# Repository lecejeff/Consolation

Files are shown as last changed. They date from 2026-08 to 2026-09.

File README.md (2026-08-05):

# Consolation
Consolation [Console Emulation] project goal is to create a portable emulation device 100% open-source and designed for cost effectiveness and accessibility.

Based on Raspberry Pi Compute Module 5 as core processor

Based on Raspberry Pi RP2350A as joystick controller re-using GP2040-CE FW

Based on Texas Instruments BQ25640 as USB-C PD solution and battery charger

Based on Nuvoton NAU88C22 audio codec

Consolation is a french word for:

1 : the act or an instance of consoling : the state of being consoled : comfort

2 : something that consoles

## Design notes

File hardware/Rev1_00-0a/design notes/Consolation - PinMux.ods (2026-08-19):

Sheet: CM5 MUX
Compute module 5
PIN | Pull? | ALT0 | ALT1 | ALT2 | ALT3 | ALT4 | ALT5 | ALT6 | ALT7 | ALT8 |  |  | Implemented?
GPIO0 | HIGH | SPI0_SIO[3] | DPI_PCLK | UART1_TX | I2C0_SDA |  | SYS_RIO[0] | PROC_RIO[0] | PIO[0] | SPI2_CSn[0] | SDA0 | Normally used for HAT and CSI0 / DSI0. | Yes
GPIO1 | HIGH | SPI0_SIO[2] | DPI_DE | UART1_RX | I2C0_SCL |  | SYS_RIO[1] | PROC_RIO[1] | PIO[1] | SPI2_SIO[1] | SCL0 | Normally used for HAT and CSI0 / DSI0. | Yes
GPIO2 | HIGH | SPI0_CSn[3] | DPI_VSYNC | UART1_CTS | I2C1_SDA | UART0_IR_RX | SYS_RIO[2] | PROC_RIO[2] | PIO[2] | SPI2_SIO[0] | GPIO2 | 1.8V internal pull-up resistors to GPIO_VREF | Yes
GPIO3 | HIGH | SPI0_CSn[2] | DPI_HSYNC | UART1_RTS | I2C1_SCL | UART0_IR_TX | SYS_RIO[3] | PROC_RIO[3] | PIO[3] | SPI2_SCLK | GPIO3 | 1.8V internal pull-up resistors to GPIO_VREF | Yes
GPIO4 | HIGH | GPCLK[0] | DPI_D0 | UART2_TX | I2C2_SDA | UART0_RI | SYS_RIO[4] | PROC_RIO[4] | PIO[4] | SPI3_CSn[0 | SDA2 | System I2C bus | Yes
GPIO5 | HIGH | GPCLK[1] | DPI_D1 | UART2_RX | I2C2_SCL | UART0_DTR | SYS_RIO[5] | PROC_RIO[5] | PIO[5] | SPI3_SIO[1] | SCL2 | System I2C bus | Yes
GPIO6 | HIGH | GPCLK[2] | DPI_D2 | UART2_CTS | I2C3_SDA | UART0_DCD | SYS_RIO[6] | PROC_RIO[6] | PIO[6] | SPI3_SIO[0] | GPIO6 | BAT charger INT input | Yes
GPIO7 | HIGH | SPI0_CSn[1] | DPI_D3 | UART2_RTS | I2C3_SCL | UART0_DSR | SYS_RIO[7] | PROC_RIO[7] | PIO[7] | SPI3_SCLK
GPIO8 | HIGH | SPI0_CSn[0] | DPI_D4 | UART3_TX | I2C0_SDA |  | SYS_RIO[8] | PROC_RIO[8] | PIO[8] | SPI4_CSn[0] | GPIO8 | BT_DISABLE | Yes
GPIO9 | LOW | SPI0_SIO[1] | DPI_D5 | UART3_RX | I2C0_SCL |  | SYS_RIO[9] | PROC_RIO[9] | PIO[9] | SPI4_MISO | GPIO9 | PPS_RTC (WATCHDOG) | Yes
GPIO10 | LOW | SPI0_SIO[0] | DPI_D6 | UART3_CTS | I2C1_SDA |  | SYS_RIO[10] | PROC_RIO[10] | PIO[10] | SPI4_MOSI | GPIO10 | RP2350_USB_BOOT | Yes
GPIO11 | LOW | SPI0_SCLK | DPI_D7 | UART3_RTS | I2C1_SCL |  | SYS_RIO[11] | PROC_RIO[11] | PIO[11] | SPI4_SCLK | GPIO11 | WL_DISABLE
GPIO12 | LOW | PMW0[0] | DPI_D8 | UART4_TX | I2C2_SDA | AUDIO_OUT_L | SYS_RIO[12] | PROC_RIO[12] | PIO[12] | SPI5_CSn[0] | PWM0_0 | MIPI-DSI PWM backlight | Yes
GPIO13 | LOW | PMW0[1] | DPI_D9 | UART4_RX | I2C2_SCL | AUDIO_OUT_R | SYS_RIO[13] | PROC_RIO[13] | PIO[13] | SPI5_SIO[1] | GPIO13 | VOLUME UP BUTTON | Yes
GPIO14 | LOW | PMW0[2] | DPI_D10 | UART4_CTS | I2C3_SDA | UART0_TX | SYS_RIO[14] | PROC_RIO[14] | PIO[14] | SPI5_SIO[0] | TXD0 | UART debug console (native in linux) | Yes
GPIO15 | LOW | PMW0[3] | DPI_D11 | UART4_RTS | I2C3_SCL | UART0_RX | SYS_RIO[15] | PROC_RIO[15] | PIO[15] | SPI5_SCLK | RXD0 | UART debug console (native in linux) | Yes
GPIO16 | LOW | SPI1_CSn[2] | DPI_D12 |  |  | UART0_CTS | SYS_RIO[16] | PROC_RIO[16] | PIO[16] |  | GPIO16 | VOLUME DOWN BUTTON | Yes
GPIO17 | LOW | SPI1_CSn[1] | DPI_D13 |  |  | UART0_RTS | SYS_RIO[17] | PROC_RIO[17] | PIO[17]
GPIO18 | LOW | SPI1_CSn[0] | DPI_D14 | I2S0_SCLK | PWM0[2] | I2S1_SCLK | SYS_RIO[18] | PROC_RIO[18] | PIO[18] | GPCLK[1] | PCM_CLK | I2S NAU8822 | Yes
GPIO19 | LOW | SPI1_SIO[1] | DPI_D15 | I2S0_WS | PWM0[3] | I2S1_WS | SYS_RIO[19] | PROC_RIO[19] | PIO[19] |  | PCM_FS | I2S NAU8822 | Yes
GPIO20 | LOW | SPI1_SIO[0] | DPI_D16 | I2S0_SDI[0] | GPCLK[0] | I2S1_SDI[0] | SYS_RIO[20] | PROC_RIO[20] | PIO[20] |  | PCM_DIN | I2S NAU8822 | Yes
GPIO21 | LOW | SPI1_SCLK | DPI_D17 | I2S0_SDO[0] | GPCLK[1] | I2S1_SDO[0] | SYS_RIO[21] | PROC_RIO[21] | PIO[21] |  | PCM_DOUT | I2S NAU8822 | Yes
GPIO22 | LOW | SDIO0_CLK | DPI_D18 | I2S0_SDI[1] | I2C3_SDA | I2S1_SDI[1] | SYS_RIO[22] | PROC_RIO[22] | PIO[22] |  | GPIO22 | BAT CHRG PG | Yes
GPIO23 | LOW | SDIO0_CMD | DPI_D19 | I2S0_SDO[1] | I2C3_SCL | I2S1_SDO[1] | SYS_RIO[23] | PROC_RIO[23] | PIO[23] |  | GPIO23 | Shutdown control | Yes
GPIO24 | LOW | SDIO0_DAT0 | DPI_D20 | I2S0_SDI[2] |  | I2S1_SDI[2] | SYS_RIO[24] | PROC_RIO[24] | PIO[24] | SPI2_CSn[1]
GPIO25 | LOW | SDIO0_DAT1 | DPI_D21 | I2S0_SDO[2] | AUDIO_IN_CLK | I2S1_SDO[2] | SYS_RIO[25] | PROC_RIO[25] | PIO[25] | SPI3_CSn[1] | GPIO25 | Battery Charger Enable | Yes
GPIO26 | LOW | SDIO0_DAT2 | DPI_D22 | I2S0_SDI[3] | AUDIO_IN_DAT0 | I2S1_SDI[3] | SYS_RIO[26] | PROC_RIO[26] | PIO[26] | SPI5_CSn[1] | GPIO26 | RP2350 Power Enable | Yes
GPIO27 | LOW | SDIO0_DAT3 | DPI_D23 | I2S0_SDO[3] | AUDIO_IN_DAT1 | I2S1_SDO[3] | SYS_RIO[27] | PROC_RIO[27] | PIO[27] | SPI1_CSn[1]

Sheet: RP2350A
PIN # | RP2350A | Used | VDD’s | Crystal + USB | SWD | Joystick + Click | A / B / X / Y | U / D / L / R | L1 / L2 / R1 / R2 | Start / Select | Home / Extra | RPI I2C bus | UART debug | QSPI FLASH
1 | IOVDD | YES | IOVDD
2 | GPIO0 | YES |  |  |  |  |  |  |  |  |  |  | UART0 TX
3 | GPIO1 | YES |  |  |  |  |  |  |  |  |  |  | UART0 RX
4 | GPIO2 | YES |  |  |  |  |  |  |  |  |  | I2C0 SDA
5 | GPIO3 | YES |  |  |  |  |  |  |  |  |  | I2C0 SCL
6 | DVDD | YES | DVDD
7 | GPIO4 | NO
8 | GPIO5 | NO
9 | GPIO6 | YES |  |  |  |  |  |  |  |  | Home
10 | GPIO7 | YES |  |  |  |  |  |  |  |  | Extra
11 | IOVDD | YES | IOVDD
12 | GPIO8 | YES |  |  |  |  |  |  | L1
13 | GPIO9 | YES |  |  |  |  |  |  | L2
14 | GPIO10 | YES |  |  |  |  |  |  | R1
15 | GPIO11 | YES |  |  |  |  |  |  | R2
16 | GPIO12 | YES |  |  |  |  |  | U
17 | GPIO13 | YES |  |  |  |  |  | D
18 | GPIO14 | YES |  |  |  |  |  | L
19 | GPIO15 | YES |  |  |  |  |  | R
20 | IOVDD | YES | IOVDD
21 | XIN | YES |  | XIN
22 | XOUT | YES |  | XOUT
23 | DVDD | YES | DVDD
24 | SWCLK | YES |  |  | SWDCLK
25 | SWDIO | YES |  |  | SWDIO
26 | RUN | YES |  |  | #RESET
27 | GPIO16 | YES |  |  |  |  |  |  |  | Start
28 | GPIO17 | YES |  |  |  |  |  |  |  | Select
29 | GPIO18 | NO
30 | IOVDD | YES | IOVDD
31 | GPIO19 | YES |  |  |  |  | A
32 | GPIO20 | YES |  |  |  |  | B
33 | GPIO21 | YES |  |  |  |  | X
34 | GPIO22 | YES |  |  |  |  | Y
35 | GPIO23 | YES |  |  |  | J1_SW
36 | GPIO24 | YES |  | VBUS_DET
37 | GPIO25 | YES |  |  |  | J2_SW
38 | IOVDD | YES | IOVDD
39 | DVDD | YES | DVDD
40 | GPIO26_ADC0 | YES |  |  |  | J1_X
41 | GPIO27_ADC1 | YES |  |  |  | J1_Y
42 | GPIO28_ADC2 | YES |  |  |  | J2_X
43 | GPIO29_ADC3 | YES |  |  |  | J2_Y
44 | ADC_AVDD | YES | ADC AVDD
45 | IOVDD | YES | IOVDD
46 | VREG_AVDD | YES | VREG AVDD
47 | VREG_PGND | YES | PGND
48 | VREG_LX | YES | VREG LX
49 | VREG_VIN | YES | VREG IN
50 | VREG_FB | YES | VREG FB
51 | USB_DM | YES |  | USB D-
52 | USB_DP | YES |  | USB D+
53 | USB_OTP_VDD | YES | USB VDD
54 | QSPI_IOVDD | YES | QSPI VDD
55 | QSPI_SD3 | YES |  |  |  |  |  |  |  |  |  |  |  | QSPI SD3
56 | QSPI_SCLK | YES |  |  |  |  |  |  |  |  |  |  |  | QSPI SCLK
57 | QSPI_SD0 | YES |  |  |  |  |  |  |  |  |  |  |  | QSPI SD0
58 | QSPI_SD2 | YES |  |  |  |  |  |  |  |  |  |  |  | QSPI SD2
59 | QSPI_SD1 | YES |  |  |  |  |  |  |  |  |  |  |  | QSPI SD1
60 | QSPI_SS | YES |  |  |  |  |  |  |  |  |  |  |  | QSPI SS
 |  | 3

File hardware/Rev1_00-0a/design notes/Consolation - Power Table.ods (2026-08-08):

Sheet: Purpose
Purpose | Engineering documentation to assess power supplies voltage compliance, current draw, power draw, efficiency and estimate margin for Consolation project
Revision | Initial revision 2026-07-19 Author: Jean-Francois Bilodeau, P.Eng #6022173
Project | Consolation [Console Emulation]

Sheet: Dependencies
Consolation [Console Emulation] | Supply name : VBAT |  |  | Consolation [Console Emulation] | VSYS |  |  | Consolation [Console Emulation] | 5V0
Parameters | Min | Nom | Max | Parameters | Min | Nom | Max | Parameters | Min | Nom | Max
Input voltage (V) | N/A | N/A | N/A | Input voltage (V) | 2.750 | 3.700 | 4.200 | Input voltage (V) | 3.520 | 3.750 | 4.000
Input current (mA) | N/A | N/A | N/A | Input current (mA) | 531.020 | 2341.576 | 3738.698 | Input current (mA) | 169.317 | 1490.033 | 2468.688
Quiescent current (mA) | N/A | N/A | N/A | Quiescent current (mA) | 0.8 | 0.9 | 1.4 | Quiescent current (mA) | 0.8 | 0.9 | 1.4
Input power (W) | N/A | N/A | N/A | Input power (W) | 1.460 | 8.664 | 15.703 | Input power (W) | 0.596 | 5.588 | 9.875
Efficiency | N/A | N/A | N/A | Efficiency | 92.00% | 90.00% | 88.00% | Efficiency | 91% | 90% | 90%
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

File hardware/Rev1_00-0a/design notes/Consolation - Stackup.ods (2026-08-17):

90R microstrip differential pair | 90R stripline differential pair
100R microstrip differential pair | 100R stripline differential pair

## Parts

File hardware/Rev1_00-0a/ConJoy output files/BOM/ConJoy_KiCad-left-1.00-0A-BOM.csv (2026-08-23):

Reference | Qty | Value | DNP | Exclude from BOM | Exclude from Board | Footprint | Manufacturer | Manufacturer Part Number | Distributor | Distributor Part Number | Datasheet
C1,C3 | 2 | 1u |  |  |  | footprint:CAP_NONPOL_0805 | YAGEO | CC0805KKX7R9BB105 | DigiKey | 311-1886-1-ND | https://www.yageogroup.com/content/datasheet/asset/file/UPY-GPHC_X7R_6_3V-TO-250V
S1,S2,S3,S4,S5 | 5 | EVQ-Q2P03W |  |  |  | footprint:EVQQ2 | Panasonic Industry | EVQ-Q2P03W | DigiKey | P12949SCT-ND | https://www3.panasonic.biz/ac/cdn/e/control/switch/light-touch/catalog/sw_lt_eng_6s_th.pdf
C2 | 1 | 0.1u |  |  |  | footprint:CAP_NONPOL_0402 | Murata Electronics | GRM155R71H104KE14D | DigiKey | 490-10700-1-ND | https://search.murata.co.jp/Ceramy/image/img/A01X/G101/ENG/GRM155R71H104KE14-01.pdf
J4 | 1 | 5051102291 |  |  |  | footprint:5051102291 | Molex | 5051102291 | DigiKey | WM11288CT-ND | https://www.molex.com/content/dam/molex/molex-dot-com/products/automated/en-us/salesdrawingpdf/505/505110/5051102291_sd.pdf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
J2 | 1 | 0532610271 |  |  |  | footprint:0532610271 | Molex | 0532610271 | DigiKey | WM7620CT-ND | https://www.molex.com/content/dam/molex/molex-dot-com/products/automated/en-us/salesdrawingpdf/532/53261/532610271_sd.pdf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
S6,S7,S8 | 3 | TL1014BF160QG |  |  |  | footprint:TL1014B | E-Switch | TL1014BF160QG | DigiKey | EG5042CT-ND | https://configured-product-images.s3.amazonaws.com/Datasheets/TL1014.pdf
D1 | 1 | MMSZ5226B-7-F |  |  |  | footprint:SOD-123 | Diodes Incorporated | MMSZ5226B-7-F | DigiKey | MMSZ5226B-FDICT-ND | https://www.diodes.com/assets/Datasheets/ds18010.pdf
J3 | 1 | SFV5R-1STE1HLF |  |  |  | footprint:SFV5R-1ST | Amphenol ICC (FCI) | SFV5R-1STE1HLF | DigiKey | 609-4330-1-ND | https://cdn.amphenol-cs.com/media/wysiwyg/files/drawing/10171070.pdf

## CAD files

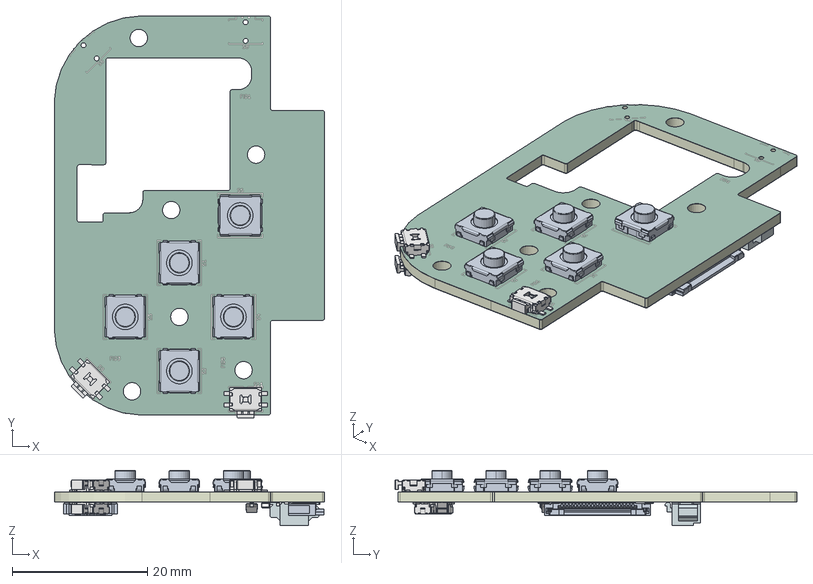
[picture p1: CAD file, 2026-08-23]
hardware/Rev1_00-0a/ConJoy output files/STEP/ConJoy-1.00-0A-STEP-RIGHT.step
40.0 x 59.4 x 8.18 mm
evqq2-bfkpuy-03w_ x 5
TL1014BFxxxQG x 3
sod123
ConJoy-1.00-0A-STEP-RIGHT 1.10
0402_capacitor
0805_cap x 2
ConJoy_KiCad_silkscreen x 2
ConJoy_KiCad_soldermask x 2
ConJoy_KiCad_PCB

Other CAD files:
hardware/Rev1_00-0a/ConJoy output files/STEP/ConJoy-1.00-0A-STEP-LEFT.step

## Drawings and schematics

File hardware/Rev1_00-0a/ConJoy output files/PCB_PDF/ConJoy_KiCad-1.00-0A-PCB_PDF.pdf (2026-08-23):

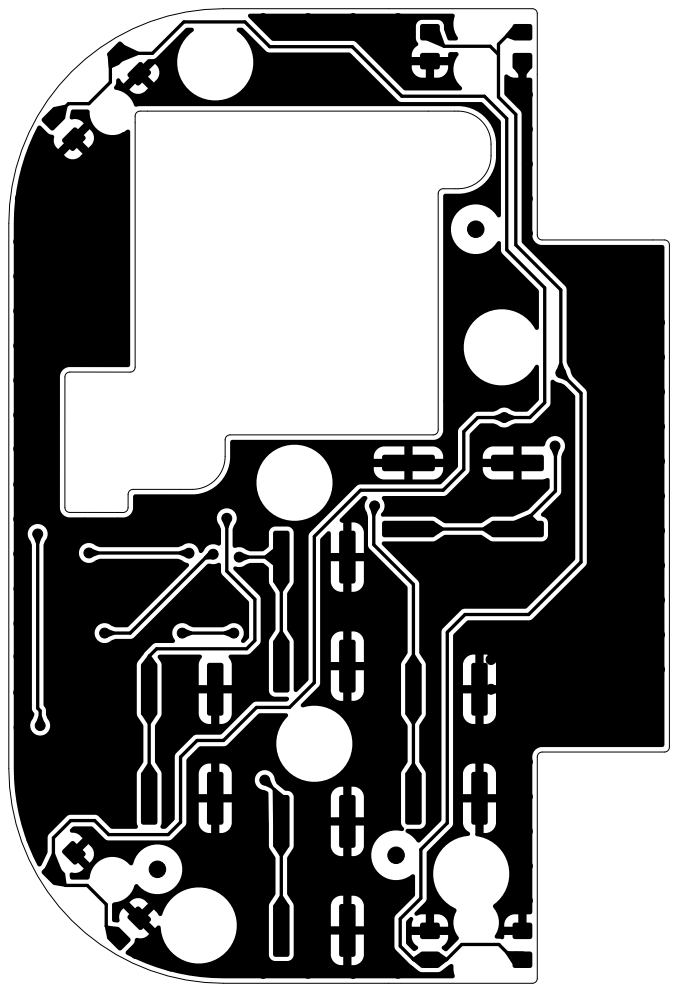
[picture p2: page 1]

Designed by: Jean-Francois Bilodeau P.Eng #6022173 203-1690 rue des quatre-saisons Sherbrooke, Quebec, J1E0N2 KiCad Rev 10.0 Drawn by: Jean-Francois Bilodeau

Date: 2026-08-23 | Current Revision: 1.00-0A Sheet Size: A4 Project: ConJoy [Console Joystick] Sheet: 1 of 9

Sheet Title: ConJoy_KiCad.kicad_pcb | Approved by: Not applicable | Status: In Review

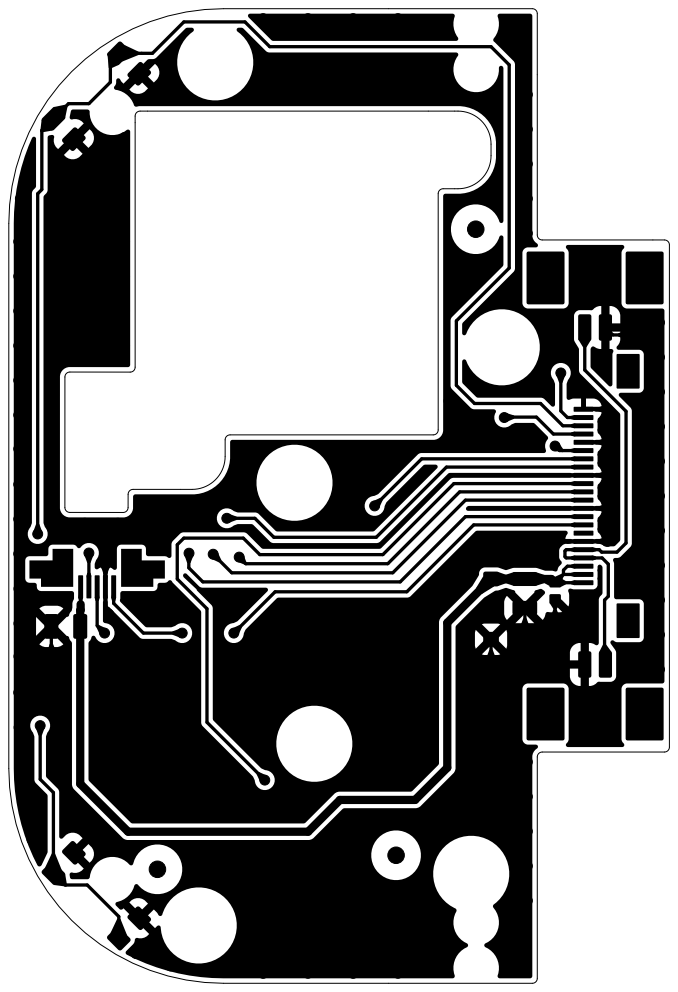
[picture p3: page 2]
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

Date: 2026-08-23 | Current Revision: 1.00-0A Sheet Size: A4 Project: ConJoy [Console Joystick] Sheet: 2 of 9

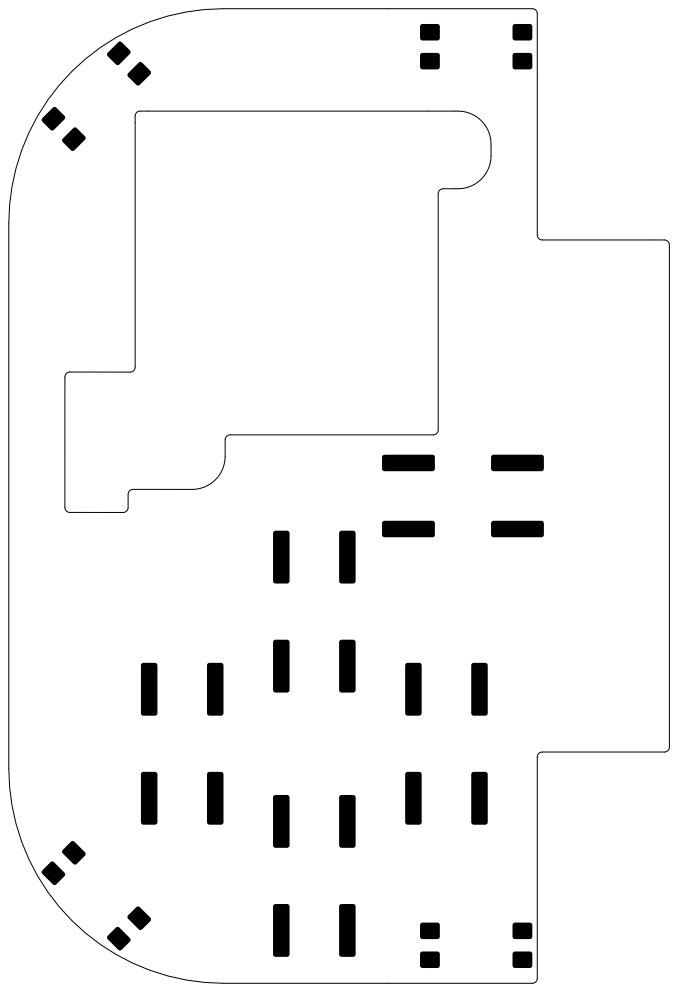
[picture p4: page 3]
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

Date: 2026-08-23 | Current Revision: 1.00-0A Sheet Size: A4 Project: ConJoy [Console Joystick] Sheet: 3 of 9

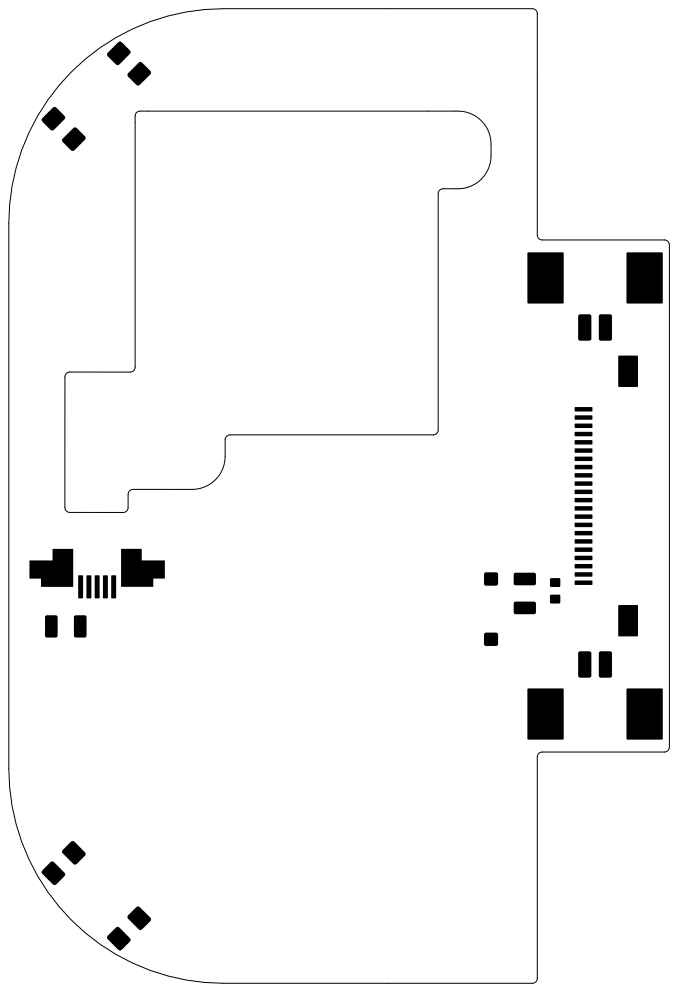
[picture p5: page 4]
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

Date: 2026-08-23 | Current Revision: 1.00-0A Sheet Size: A4 Project: ConJoy [Console Joystick] Sheet: 4 of 9

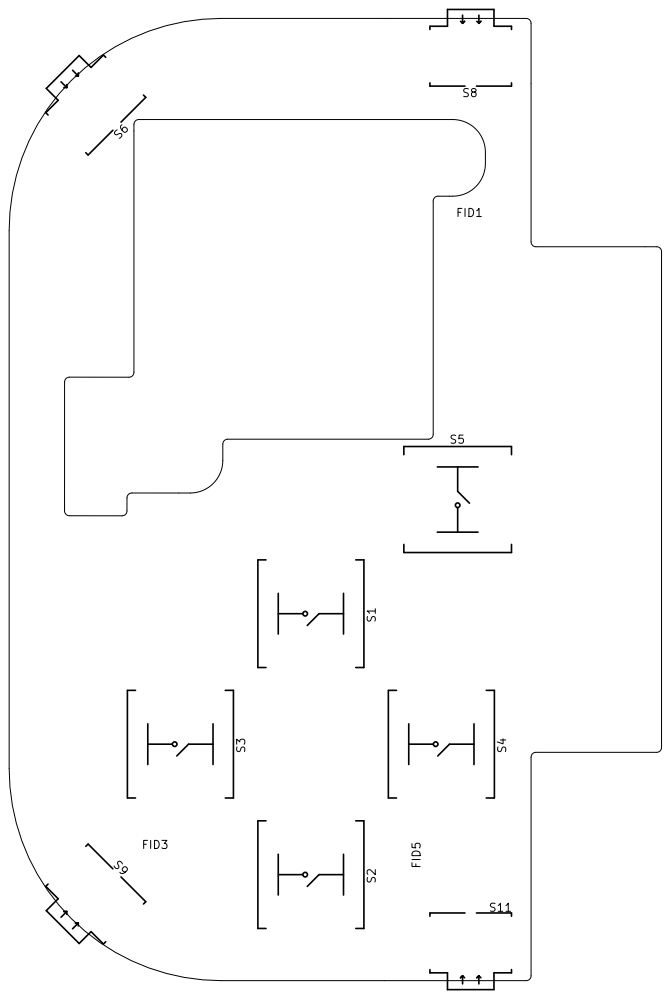
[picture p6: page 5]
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

Date: 2026-08-23 | Current Revision: 1.00-0A Sheet Size: A4 Project: ConJoy [Console Joystick] Sheet: 5 of 9

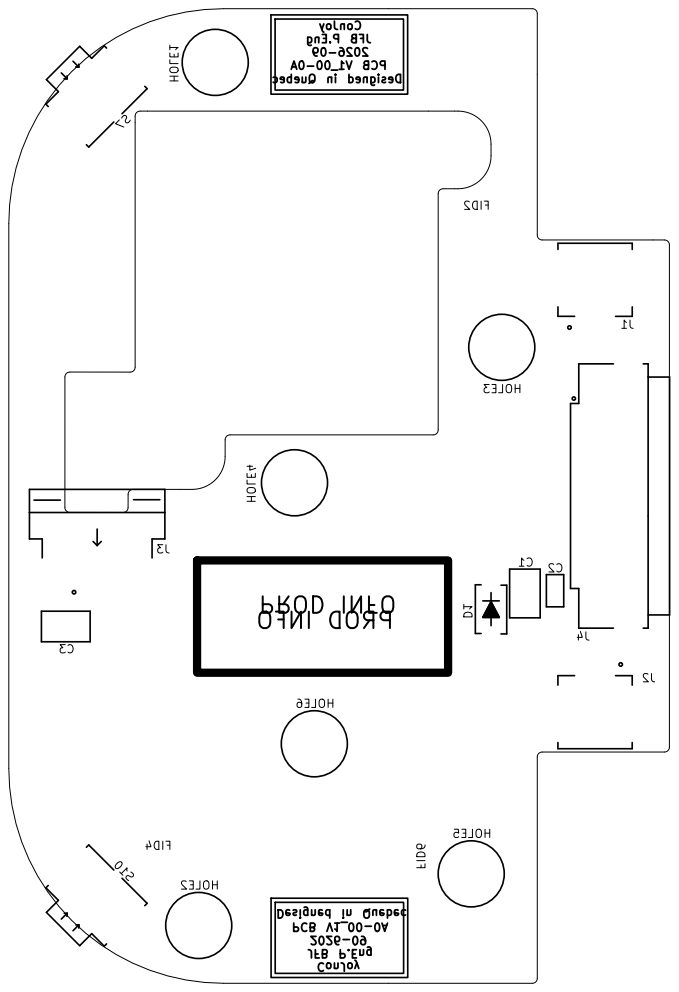
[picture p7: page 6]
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

Date: 2026-08-23 | Current Revision: 1.00-0A Sheet Size: A4 Project: ConJoy [Console Joystick] Sheet: 6 of 9

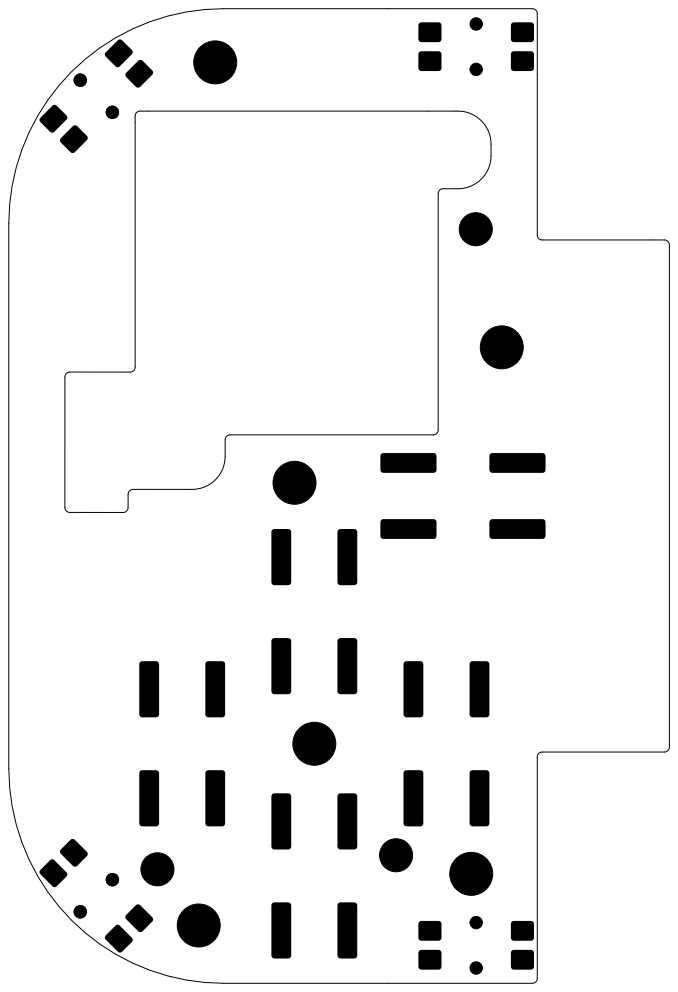
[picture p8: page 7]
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

Date: 2026-08-23 | Current Revision: 1.00-0A Sheet Size: A4 Project: ConJoy [Console Joystick] Sheet: 7 of 9

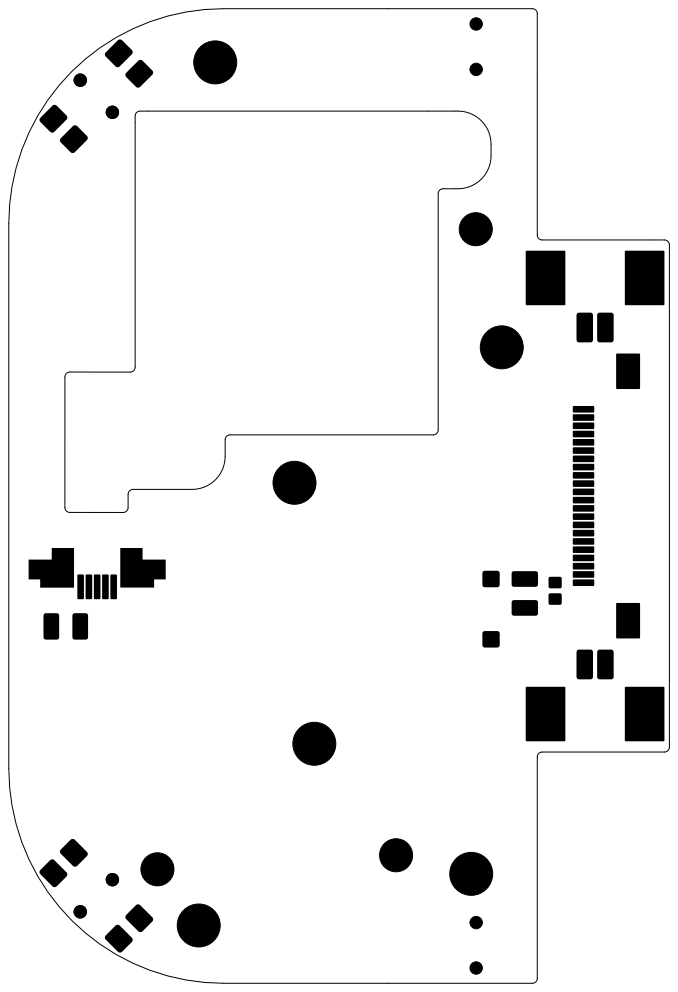
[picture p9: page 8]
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

Date: 2026-08-23 | Current Revision: 1.00-0A Sheet Size: A4 Project: ConJoy [Console Joystick] Sheet: 8 of 9

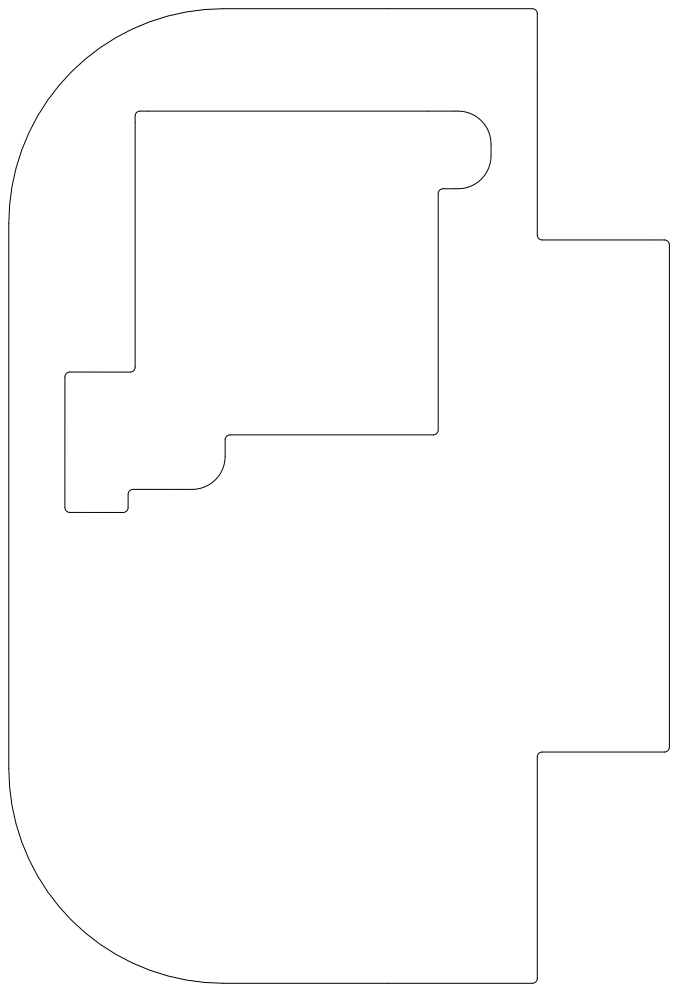
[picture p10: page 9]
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

Date: 2026-08-23 | Current Revision: 1.00-0A Sheet Size: A4 Project: ConJoy [Console Joystick] Sheet: 9 of 9

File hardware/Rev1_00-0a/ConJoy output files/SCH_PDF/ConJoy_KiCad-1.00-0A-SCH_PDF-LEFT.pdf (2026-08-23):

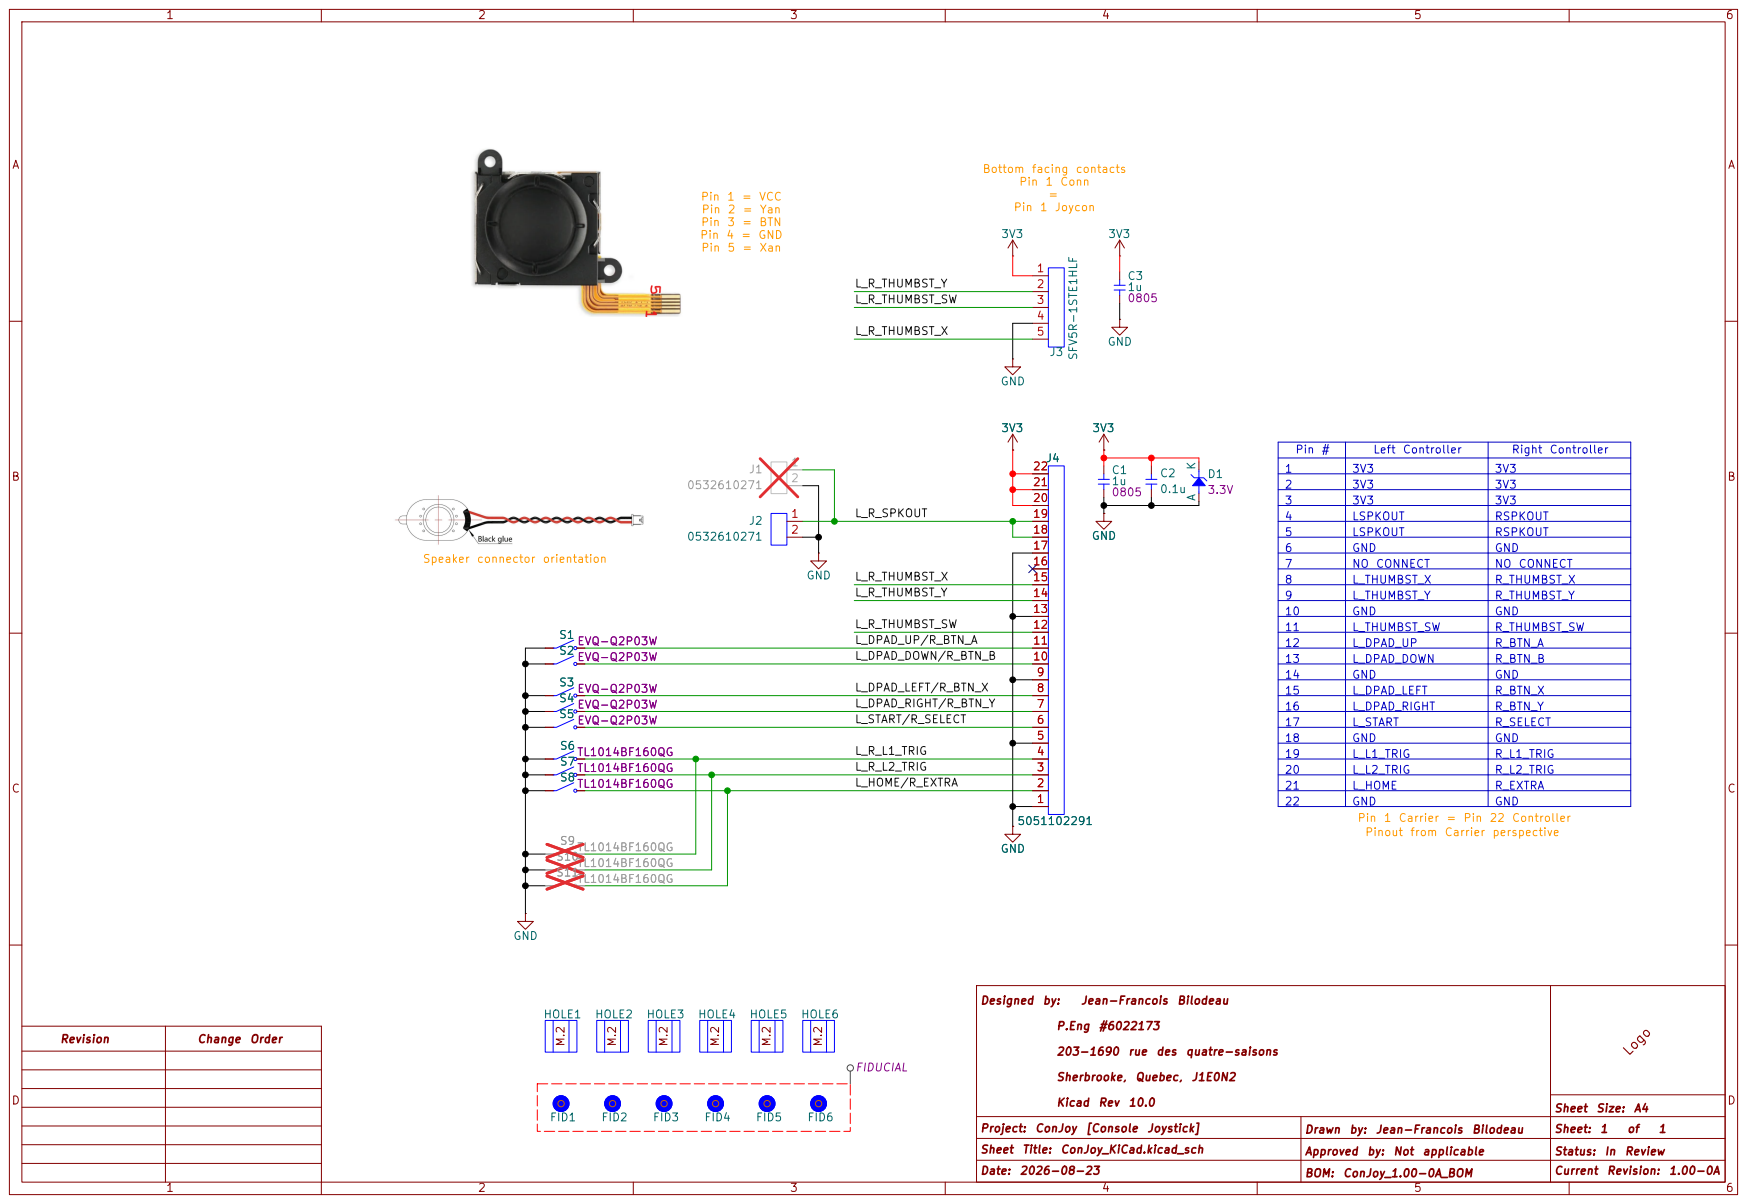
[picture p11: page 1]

Bottom facing contacts Pin 1 Conn =

Pin 1 = VCC
Pin 2 = Yan Pin 3 = BTN

Pin 5 = Xan Speaker connector orientation S3 EVQ-Q2P03W S4 EVQ-Q2P03W S5 EVQ-Q2P03W

20 | L_L2_TRIG | R_L2_TRIG
21 | L_HOME GND | R_EXTRA 22 GND

Pin 1 Carrier = Pin 22 Controller
Pinout from Carrier perspective

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

Date: 2026-08-23 | Current Revision: 1.00-0A Sheet Size: A4 Project: ConJoy [Console Joystick] Sheet: 1 of 1

Sheet Title: ConJoy_KiCad.kicad_sch | Approved by: Not applicable | Status: In Review

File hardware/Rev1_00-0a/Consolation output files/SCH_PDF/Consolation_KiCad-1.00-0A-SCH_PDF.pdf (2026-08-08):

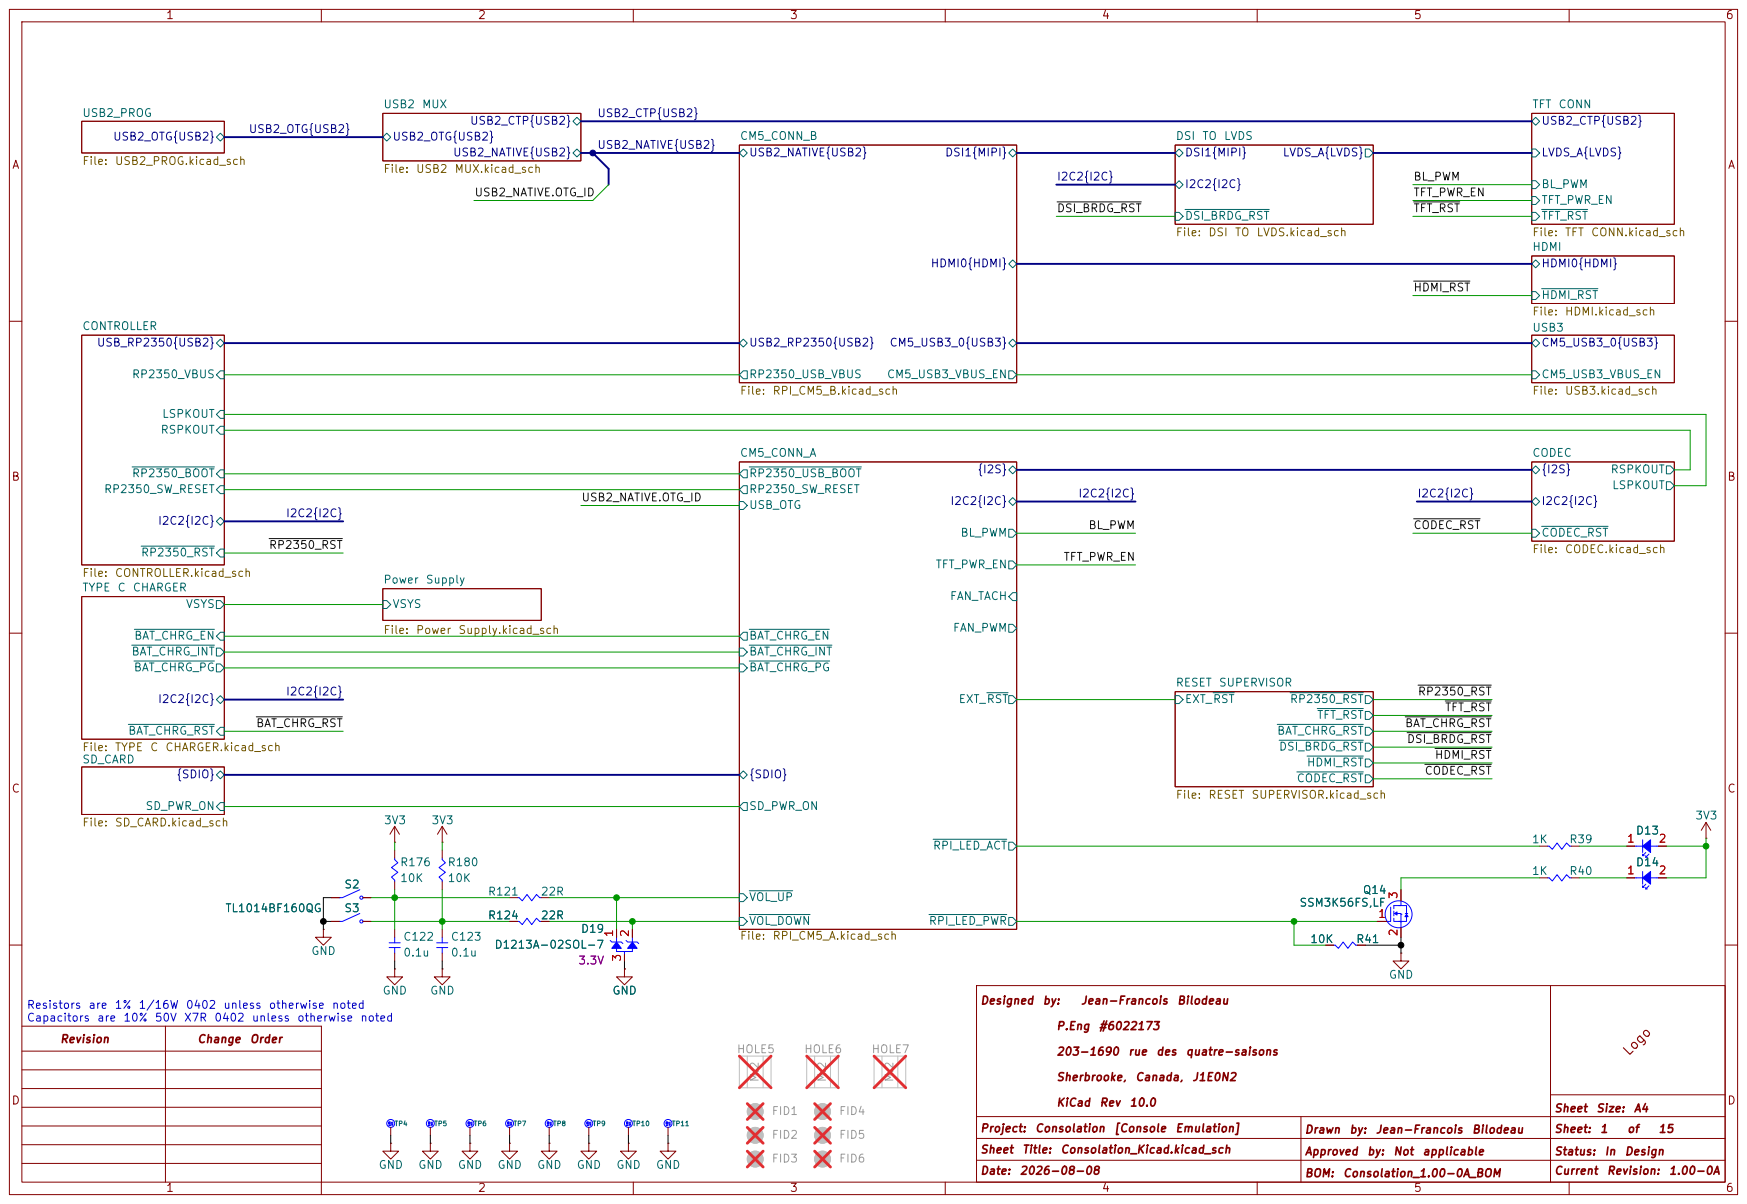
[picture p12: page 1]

HDMI0{HDMI} HDMI_RST HDMI File: HDMI.kicad_sch USB2_CTP{USB2}

File: DSI TO LVDS.kicad_sch BAT_CHRG_EN

Designed by: Jean-Francois Bilodeau P.Eng #6022173 203-1690 rue des quatre-saisons Sherbrooke, Canada, J1E0N2 KiCad Rev 10.0 Drawn by: Jean-Francois Bilodeau

Date: 2026-08-08 | Current Revision: 1.00-0A Sheet Size: A4 Project: Consolation [Console Emulation] Sheet: 1 of 15

Approved by: Not applicable

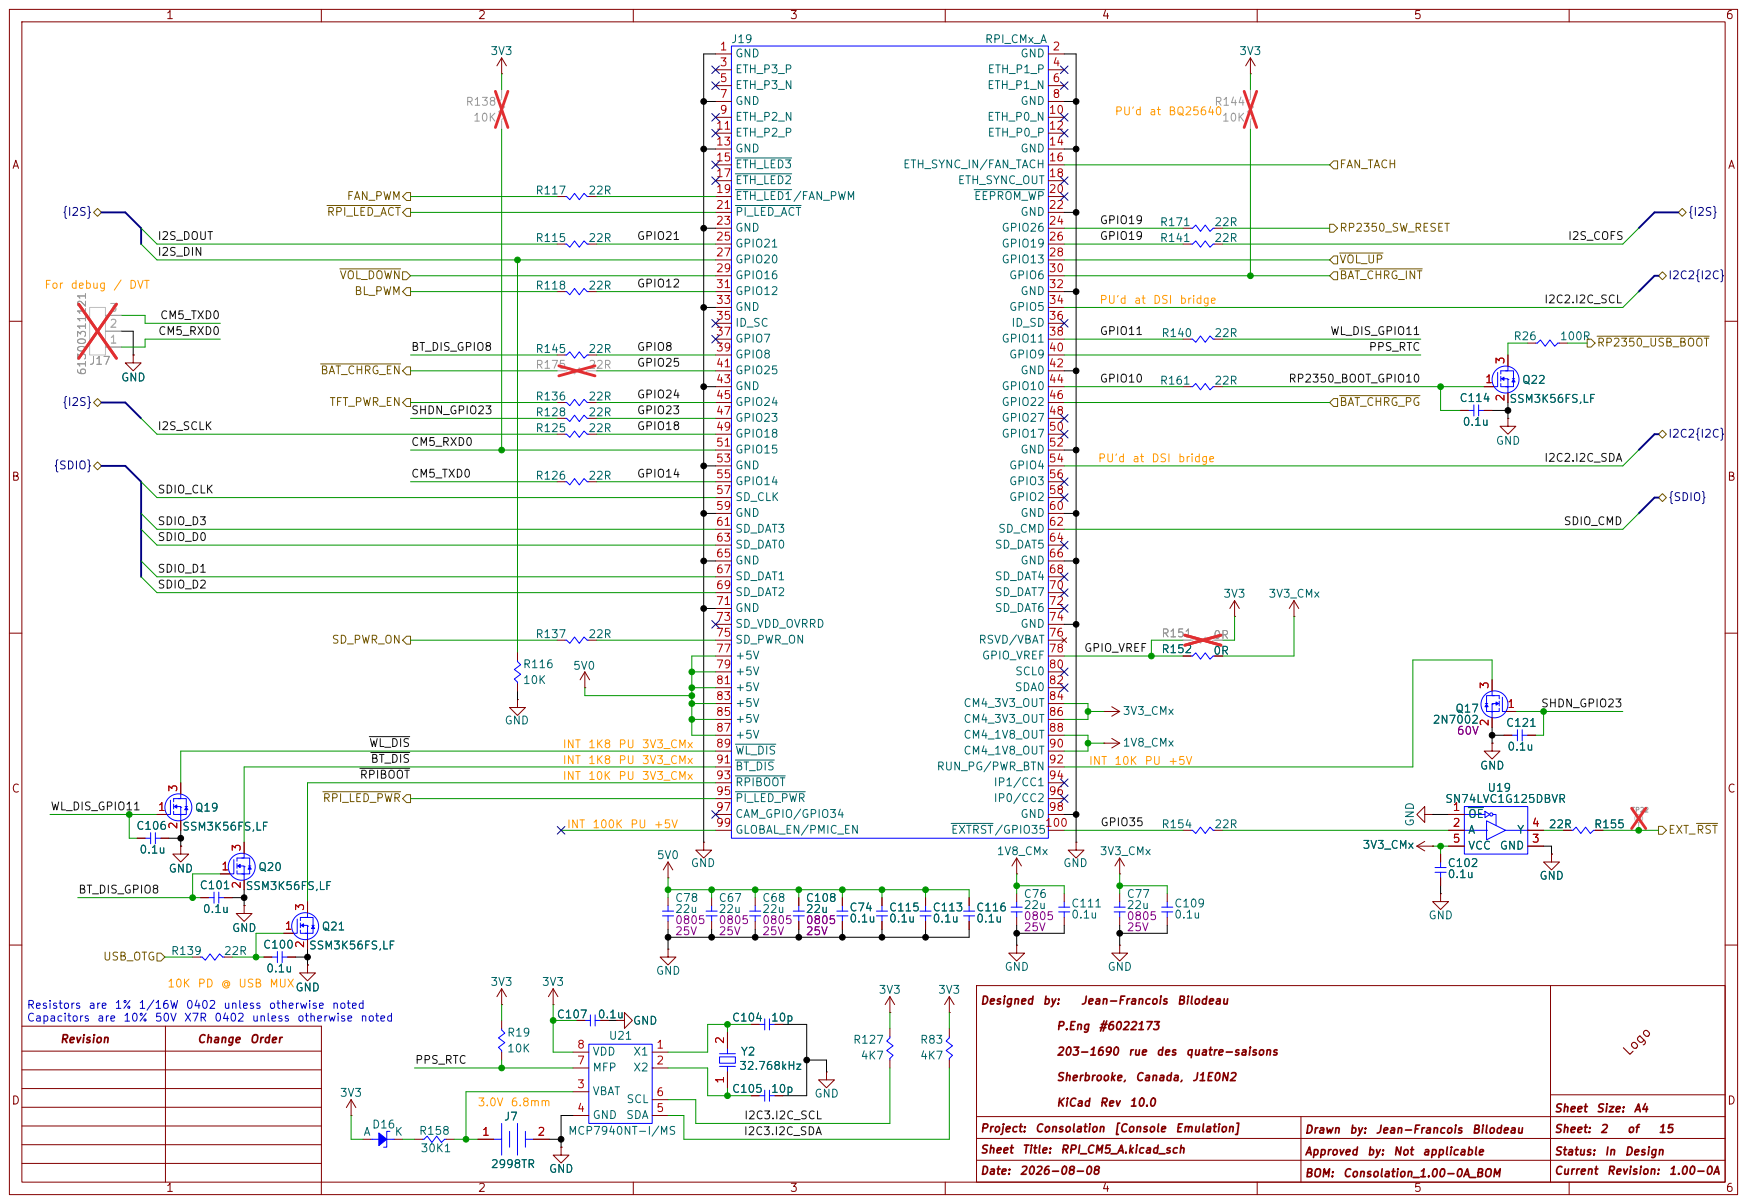
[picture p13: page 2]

INT 1K8 PU 3V3_CMx 10K PD @ USB MUX Resistors are 1% 1/16W 0402 unless otherwise noted Capacitors are 10% 50V X7R 0402 unless otherwise noted

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

Date: 2026-08-08 | Current Revision: 1.00-0A Sheet Size: A4 Project: Consolation [Console Emulation] Sheet: 2 of 15

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

Date: 2026-08-08 | Current Revision: 1.00-0A Sheet Size: A4 Project: Consolation [Console Emulation] Sheet: 3 of 15


Logo HDMI 2.1 D2+ 1 D2S 2 D2- 3 D1+ 4 D1S 5 D1- 6 D0+ 7 D0S 8 D0- 9 CK+ 10 CKS 11 CK- 12 CEC 13 UTIL/HEAC+ 14

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

Date: 2026-08-08 | Current Revision: 1.00-0A Sheet Size: A4 Project: Consolation [Console Emulation] Sheet: 4 of 15

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

Date: 2026-08-08 | Current Revision: 1.00-0A Sheet Size: A4 Project: Consolation [Console Emulation] Sheet: 5 of 15

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

Date: 2026-08-08 | Current Revision: 1.00-0A Sheet Size: A4 Project: Consolation [Console Emulation] Sheet: 6 of 15

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

Date: 2026-08-08 | Current Revision: 1.00-0A Sheet Size: A4 Project: Consolation [Console Emulation] Sheet: 7 of 15


Value TBD Has internal PD

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

Date: 2026-08-08 | Current Revision: 1.00-0A Sheet Size: A4 Project: Consolation [Console Emulation] Sheet: 8 of 15


LSPKOUT USB_RP2350{USB2} RP2350_BOOT RP2350_SW_RESET RP2350_RST
HW reset, push-pull

Pull low before releasing
SW reset to boot USB

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

Date: 2026-08-08 | Current Revision: 1.00-0A Sheet Size: A4 Project: Consolation [Console Emulation] Sheet: 9 of 15


I2C2 PU Pop'd at DSI bridge

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

Date: 2026-08-08 | Current Revision: 1.00-0A Sheet Size: A4 Project: Consolation [Console Emulation] Sheet: 10 of 15

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

Date: 2026-08-08 | Current Revision: 1.00-0A Sheet Size: A4 Project: Consolation [Console Emulation] Sheet: 11 of 15

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

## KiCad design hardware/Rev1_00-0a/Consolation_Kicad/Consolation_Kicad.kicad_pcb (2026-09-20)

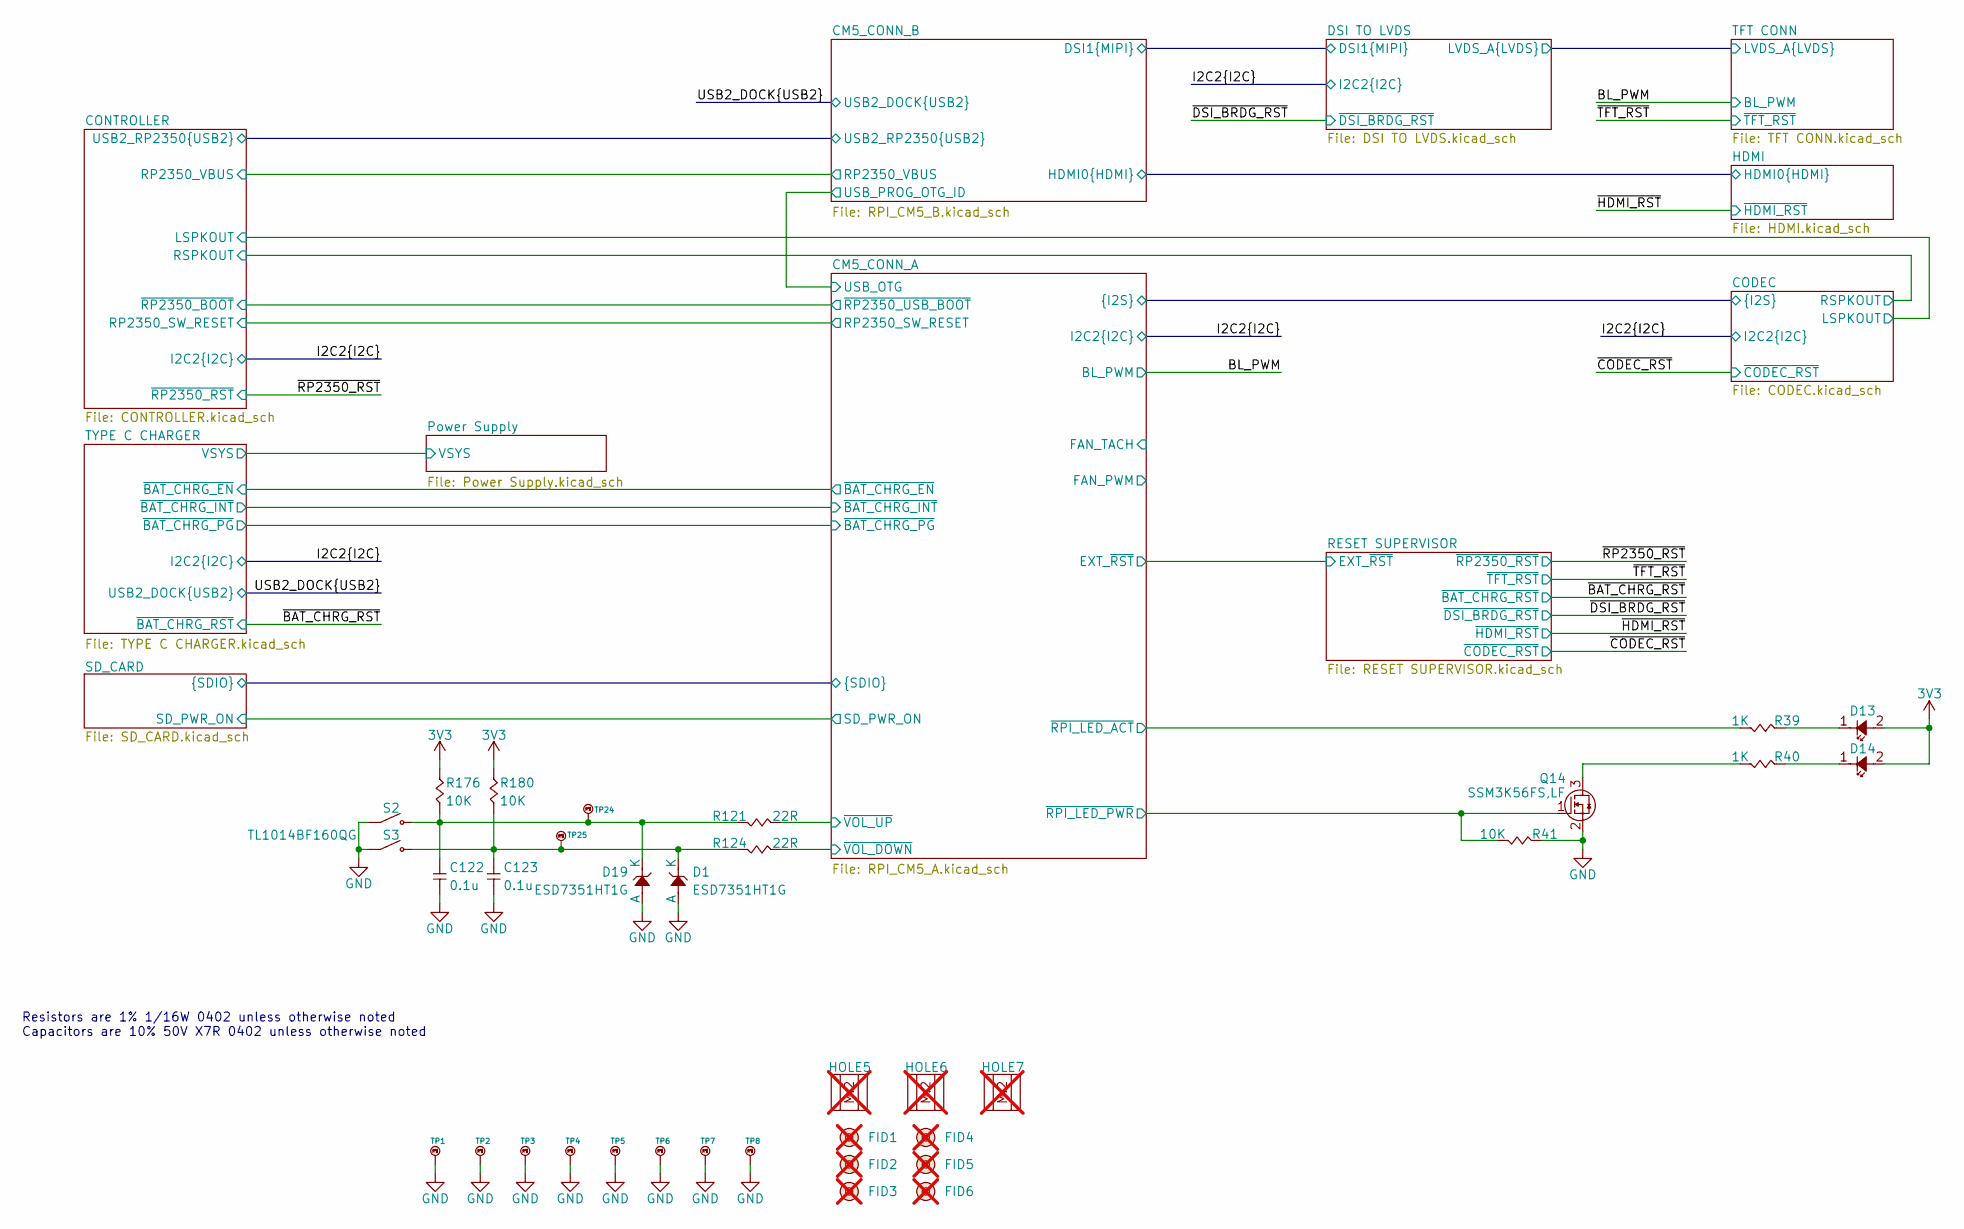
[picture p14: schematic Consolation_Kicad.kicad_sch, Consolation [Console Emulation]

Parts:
C122, C123: 0.1u; CAP_NONPOL_0402; Tolerance ±10%; Voltage Rating 50V; Manufacturer Part Number GRM155R71H104KE14D
D1, D19: ESD7351HT1G; SOD-323; Manufacturer Part Number ESD7351HT1G
D13, D14: LTST-C190KGKT; LED_0603; Tolerance NA; Manufacturer Part Number LTST-C190KGKT
FID1, FID2, FID3, FID4, FID5, FID6: FIDUCIAL; not fitted
HOLE5, HOLE6, HOLE7: NPTH_M2; not fitted
Q14: SSM3K56FS,LF; SC-75; Manufacturer Part Number SSM3K56FS,LF
R39, R40: 1K; RES_0402; Tolerance 1%; Manufacturer Part Number RC0402FR-071KL
R41, R176, R180: 10K; RES_0402; Tolerance 1%; Manufacturer Part Number RC0402FR-0710KL
R121, R124: 22R; RES_0402; Tolerance 1%; Manufacturer Part Number RC0402FR-0722RL
S2, S3: TL1014BF160QG; TL1014B; Manufacturer Part Number TL1014BF160QG
TP1, TP2, TP3, TP4, TP5, TP6, TP7, TP8, TP24, TP25: 75 mils; SMT_TP_75_MILS; Manufacturer Part Number NA

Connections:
3V3: D13.2 (A), D14.2 (A), R176.2, R180.2; also elsewhere on the board
/CM5_CONN_A/~RPI_LED_ACT: R39.2; also elsewhere on the board
/CM5_CONN_A/~RPI_LED_PWR: Q14.1 (G), R41.1; also elsewhere on the board
/CM5_CONN_A/~VOL_DOWN: R124.1; also elsewhere on the board
/CM5_CONN_A/~VOL_UP: R121.1; also elsewhere on the board
GND: C122.1, C123.1, D1.2 (A), D19.2 (A), Q14.2 (S), R41.2, S2.1, S3.1, TP1.1, TP2.1, TP3.1, TP4.1, TP5.1, TP6.1, TP7.1, TP8.1; also elsewhere on the board
unnamed: C123.2, D1.1 (K), R124.2, R180.1, S3.2, TP25.1
unnamed: D13.1 (K), R39.1
unnamed: D14.1 (K), R40.1
unnamed: C122.2, D19.1 (K), R121.2, R176.1, S2.2, TP24.1
unnamed: Q14.3 (D), R40.2

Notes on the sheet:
Resistors are 1% 1/16W 0402 unless otherwise noted Capacitors are 10% 50V X7R 0402 unless otherwise noted

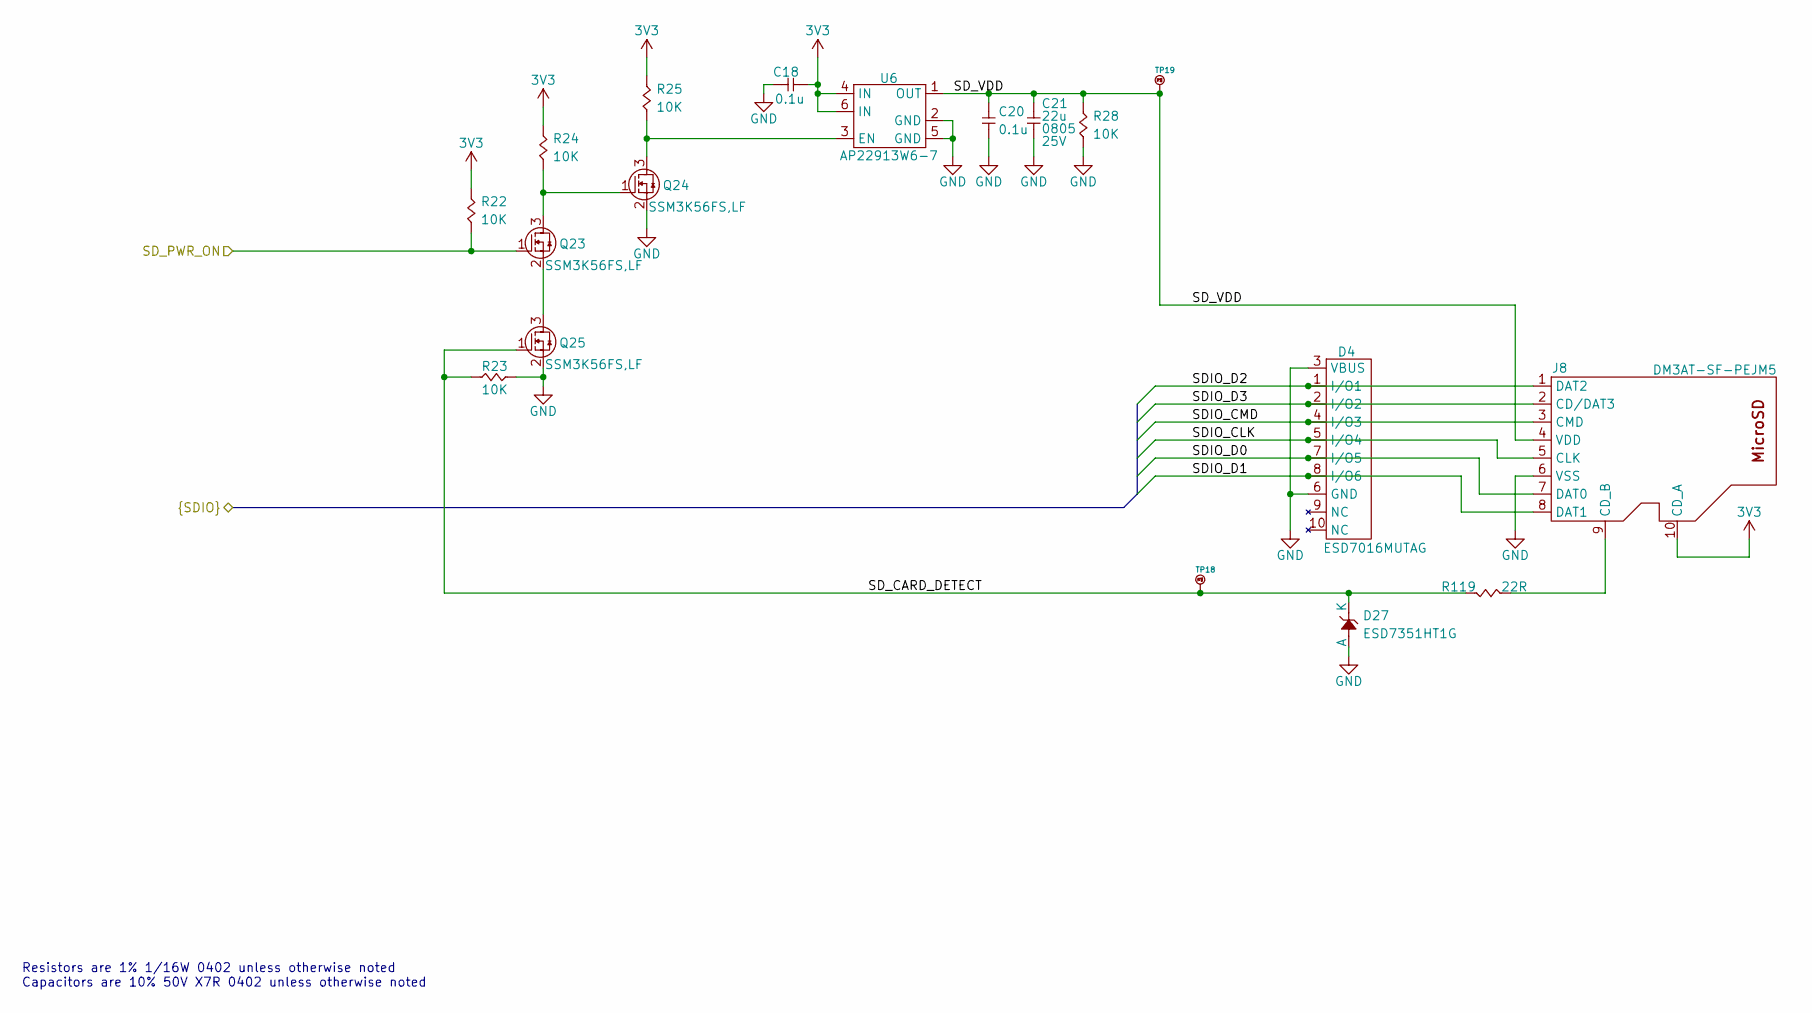
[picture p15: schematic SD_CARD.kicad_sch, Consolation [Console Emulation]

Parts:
C18, C20: 0.1u; CAP_NONPOL_0402; Tolerance ±10%; Voltage Rating 50V; Manufacturer Part Number GRM155R71H104KE14D
C21: 22u; CAP_NONPOL_0805; Tolerance ±20%; Voltage Rating 25V; Manufacturer Part Number CL21A226MAYNNNE
D4: ESD7016MUTAG; UDFN8; Manufacturer Part Number ESD7016MUTAG
D27: ESD7351HT1G; SOD-323; Manufacturer Part Number ESD7351HT1G
J8: DM3AT-SF-PEJM5; Current Rating 0.5A; Voltage Rating 125V; Manufacturer Part Number DM3AT-SF-PEJM5
Q23, Q24, Q25: SSM3K56FS,LF; SC-75; Manufacturer Part Number SSM3K56FS,LF
R22, R23, R24, R25, R28: 10K; RES_0402; Tolerance 1%; Manufacturer Part Number RC0402FR-0710KL
R119: 22R; RES_0402; Tolerance 1%; Manufacturer Part Number RC0402FR-0722RL
TP18, TP19: 75 mils; SMT_TP_75_MILS; Manufacturer Part Number NA
U6: AP22913W6-7; SOT-23-6; Load Voltage 1.5V ~ 5.5V; Manufacturer Part Number AP22913W6-7

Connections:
3V3: C18.2, J8.10 (CD_A), R22.2, R24.2, R25.2, U6.4 (IN), U6.6 (IN); also elsewhere on the board
/CM5_CONN_A/SDIO_CLK: D4.5 (I/O4), J8.5 (CLK); also elsewhere on the board
/CM5_CONN_A/SDIO_CMD: D4.4 (I/O3), J8.3 (CMD); also elsewhere on the board
/CM5_CONN_A/SDIO_D0: D4.7 (I/O5), J8.7 (DAT0); also elsewhere on the board
/CM5_CONN_A/SDIO_D1: D4.8 (I/O6), J8.8 (DAT1); also elsewhere on the board
/CM5_CONN_A/SDIO_D2: D4.1 (I/O1), J8.1 (DAT2); also elsewhere on the board
/CM5_CONN_A/SDIO_D3: D4.2 (I/O2), J8.2 (CD/DAT3); also elsewhere on the board
/CM5_CONN_A/SD_PWR_ON: Q23.1 (G), R22.1; also elsewhere on the board
/SD_CARD/SD_CARD_DETECT: D27.1 (K), Q25.1 (G), R23.2, R119.2, TP18.1
/SD_CARD/SD_VDD: C20.2, C21.2, J8.4 (VDD), R28.2, TP19.1, U6.1 (OUT)
GND: C18.1, C20.1, C21.1, D4.3 (VBUS), D4.6 (GND), D27.2 (A), J8.6 (VSS), Q24.2 (S), Q25.2 (S), R23.1, R28.1, U6.2 (GND), U6.5 (GND); also elsewhere on the board
unnamed: J8.9 (CD_B), R119.1
unnamed: Q23.3 (D), Q24.1 (G), R24.1
unnamed: Q23.2 (S), Q25.3 (D)
unnamed: Q24.3 (D), R25.1, U6.3 (EN)

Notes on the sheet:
Resistors are 1% 1/16W 0402 unless otherwise noted Capacitors are 10% 50V X7R 0402 unless otherwise noted

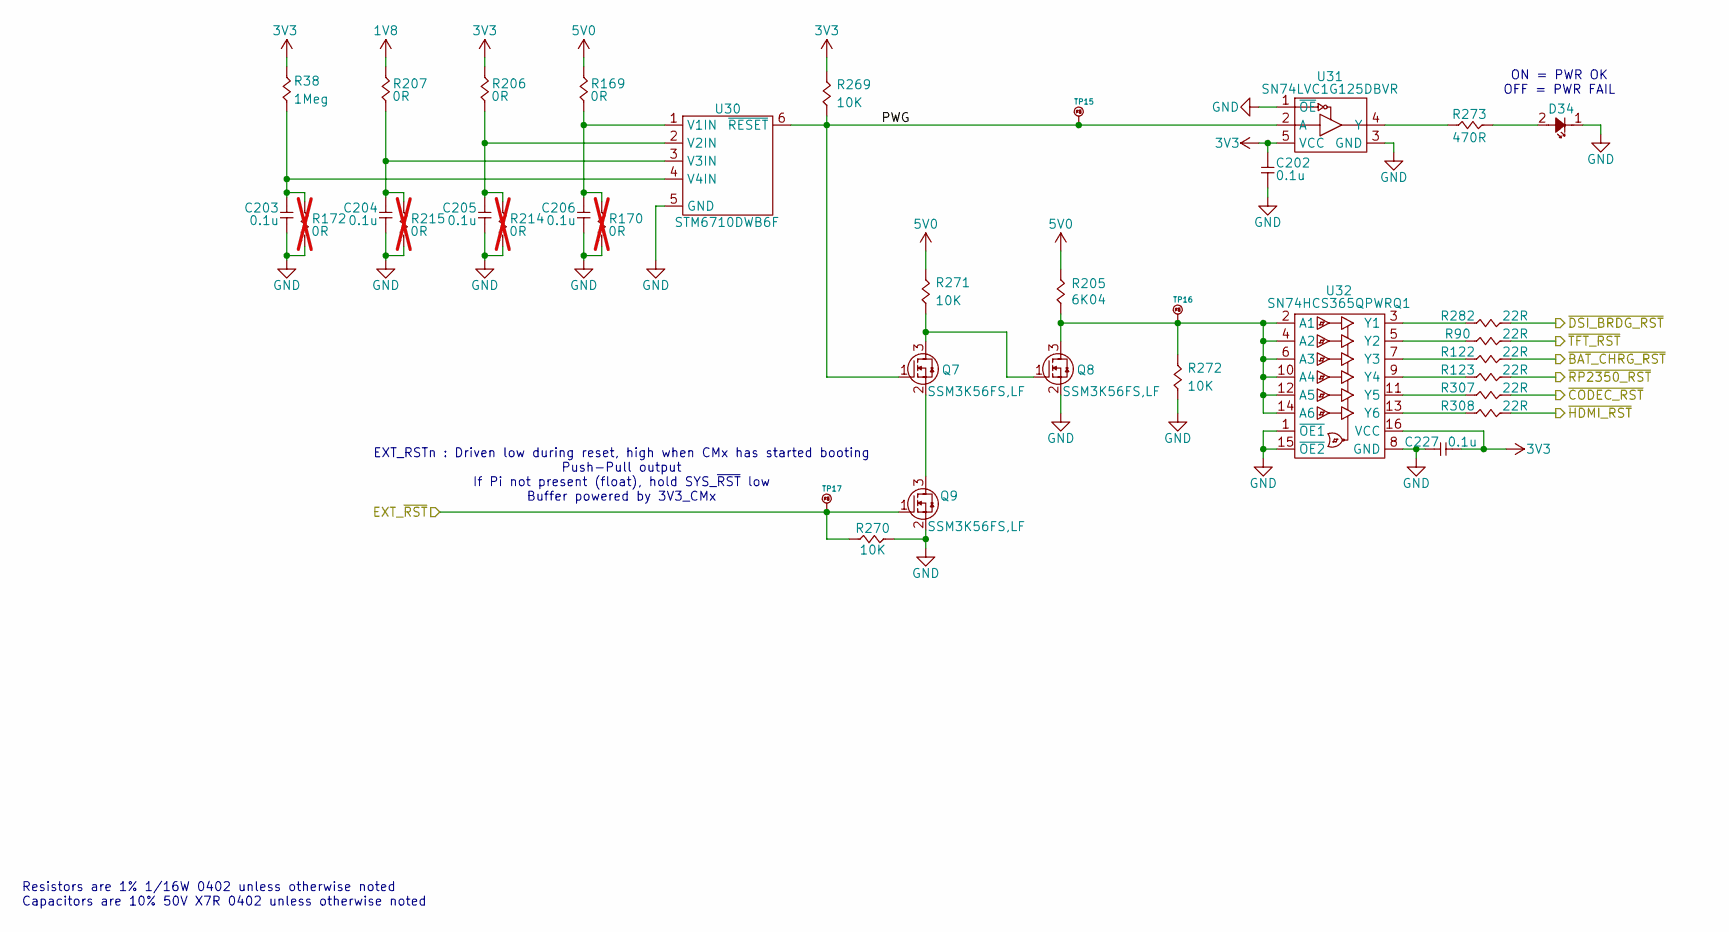
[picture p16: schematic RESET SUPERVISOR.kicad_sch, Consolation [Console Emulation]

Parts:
C202, C203, C204, C205, C206, C227: 0.1u; CAP_NONPOL_0402; Tolerance ±10%; Voltage Rating 50V; Manufacturer Part Number GRM155R71H104KE14D
D34: LTST-C190KGKT; LED_0603; Tolerance NA; Manufacturer Part Number LTST-C190KGKT
Q7, Q8, Q9: SSM3K56FS,LF; SC-75; Manufacturer Part Number SSM3K56FS,LF
R38: 1Meg; RES_0402; Tolerance 1%; Manufacturer Part Number RC0402FR-131ML
R90, R122, R123, R282, R307, R308: 22R; RES_0402; Tolerance 1%; Manufacturer Part Number RC0402FR-0722RL
R169, R206, R207: 0R; RES_0402; Tolerance 1%; Manufacturer Part Number RC0402FR-071KL
R170, R172, R214, R215: 0R; RES_0402; Tolerance 1%; Manufacturer Part Number RC0402FR-071KL; not fitted
R205: 6K04; RES_0402; Tolerance 1%; Manufacturer Part Number RC0402FR-076K04P
R269, R270, R271, R272: 10K; RES_0402; Tolerance 1%; Manufacturer Part Number RC0402FR-0710KL
R273: 470R; RES_0402; Tolerance 1%; Manufacturer Part Number RC0402FR-07470RL
TP15, TP16, TP17: 75 mils; SMT_TP_75_MILS; Manufacturer Part Number NA
U30: STM6710DWB6F; SOT-23-6; Supply Voltage 1.20V ~ 5.5V; Manufacturer Part Number STM6710DWB6F
U31: SN74LVC1G125DBVR; SOT-23-5; Supply Voltage 1.65V ~ 5.5V; Manufacturer Part Number SN74LVC1G125DBVR
U32: SN74HCS365QPWRQ1; TSSOP-16-5.8mm; Supply Voltage 2.0V ~ 6.0V; Manufacturer Part Number SN74HCS365QPWRQ1

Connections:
1V8: R207.2; also elsewhere on the board
3V3: C202.2, C227.1, R38.2, R206.2, R269.2, U31.5 (VCC), U32.16 (VCC); also elsewhere on the board
5V0: R169.2, R205.1, R271.2; also elsewhere on the board
/CM5_CONN_A/EXT_~RST: Q9.1 (G), R270.2, TP17.1; also elsewhere on the board
/RESET SUPERVISOR/PWG: Q7.1 (G), R269.1, TP15.1, U30.6 (~RESET), U31.2 (A)
/~BAT_CHRG_RST: R122.2; also elsewhere on the board
/~CODEC_RST: R307.2; also elsewhere on the board
/~DSI_BRDG_RST: R282.2; also elsewhere on the board
/~HDMI_RST: R308.2; also elsewhere on the board
/~RP2350_RST: R123.2; also elsewhere on the board
/~TFT_RST: R90.2; also elsewhere on the board
GND: C202.1, C203.1, C204.1, C205.1, C206.1, C227.2, D34.1 (K), Q8.2 (S), Q9.2 (S), R170.1, R172.1, R214.1, R215.1, R270.1, R272.1, U30.5 (GND), U31.1 (~OE), U31.3 (GND), U32.1 (~OE1), U32.8 (GND), U32.15 (~OE2); also elsewhere on the board
unnamed: D34.2 (A), R273.2
unnamed: Q7.3 (D), Q8.1 (G), R271.1
unnamed: Q7.2 (S), Q9.3 (D)
unnamed: Q8.3 (D), R205.2, R272.2, TP16.1, U32.2 (A1), U32.4 (A2), U32.6 (A3), U32.10 (A4), U32.12 (A5), U32.14 (A6)
unnamed: C206.2, R169.1, R170.2, U30.1 (V1IN)
unnamed: C205.2, R206.1, R214.2, U30.2 (V2IN)
unnamed: C204.2, R207.1, R215.2, U30.3 (V3IN)
unnamed: C203.2, R38.1, R172.2, U30.4 (V4IN)
unnamed: R273.1, U31.4 (Y)
unnamed: R282.1, U32.3 (Y1)
unnamed: R90.1, U32.5 (Y2)
unnamed: R122.1, U32.7 (Y3)
unnamed: R123.1, U32.9 (Y4)
unnamed: R307.1, U32.11 (Y5)
unnamed: R308.1, U32.13 (Y6)

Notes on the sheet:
EXT_RSTn : Driven low during reset, high when CMx has started booting Push-Pull output If Pi not present (float), hold SYS_~{RST} low Buffer powered by 3V3_CMx
ON = PWR OK OFF = PWR FAIL
Resistors are 1% 1/16W 0402 unless otherwise noted Capacitors are 10% 50V X7R 0402 unless otherwise noted

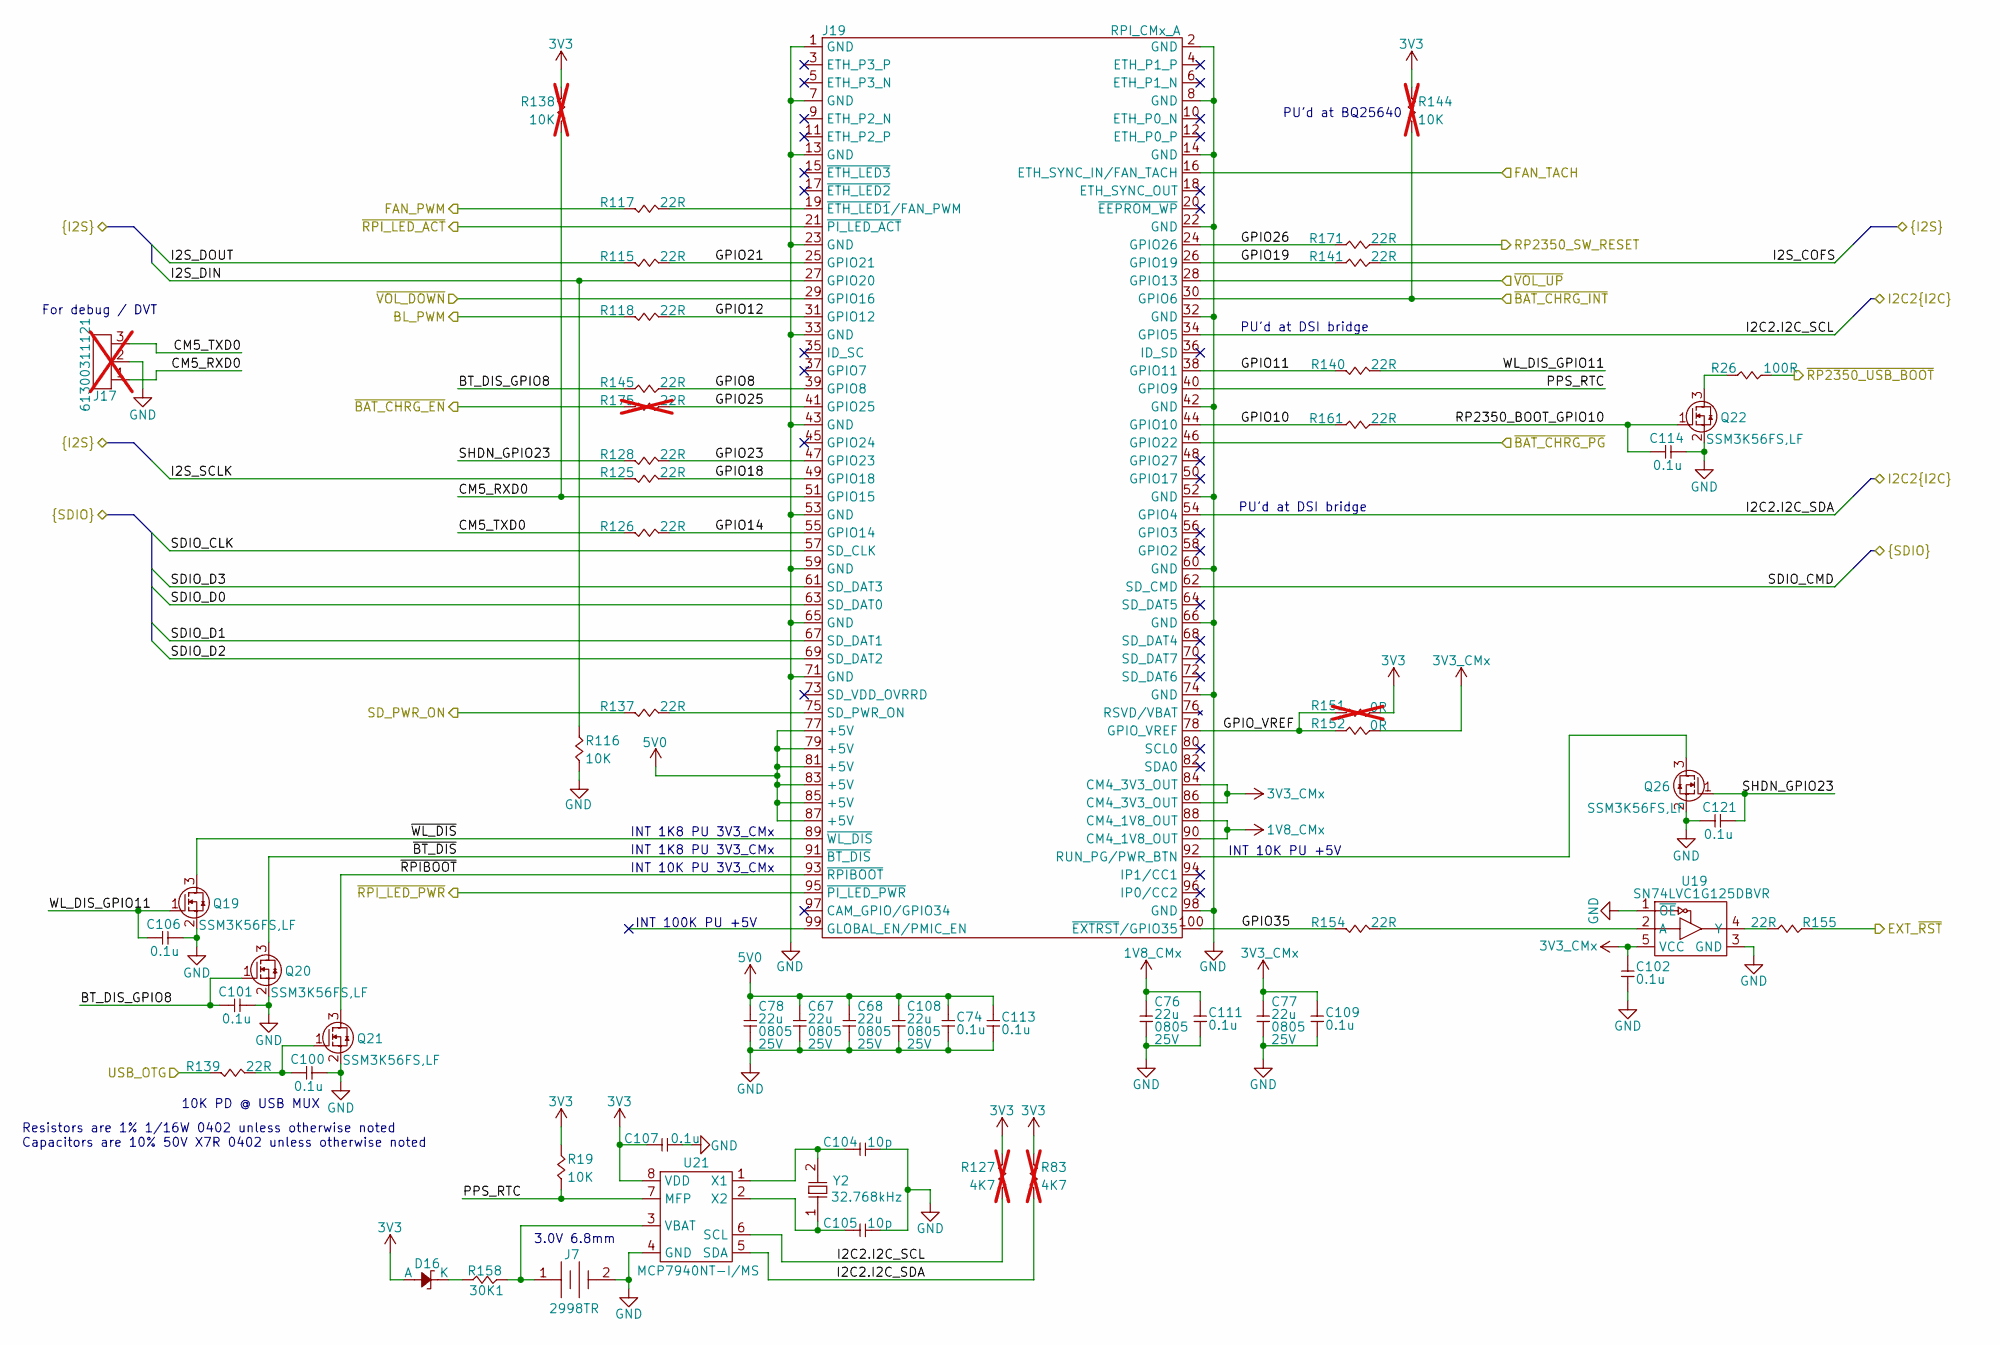
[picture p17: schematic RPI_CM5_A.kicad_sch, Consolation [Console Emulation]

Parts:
C67, C68, C76, C77, C78, C108: 22u; CAP_NONPOL_0805; Tolerance ±20%; Voltage Rating 25V; Manufacturer Part Number CL21A226MAYNNNE
C74, C100, C101, C102, C106, C107, C109, C111, C113, C114, C121: 0.1u; CAP_NONPOL_0402; Tolerance ±10%; Voltage Rating 50V; Manufacturer Part Number GRM155R71H104KE14D
C104, C105: 10p; CAP_NONPOL_0402; Tolerance ±5%; Voltage Rating 50V; Manufacturer Part Number CC0402JRNPO9BN100
D16: BAT42WS-TP; SOD-323; Tolerance NA; Manufacturer Part Number BAT42WS-TP
J7: 2998TR; Manufacturer Part Number 2998TR
J17: 61300311121; HEADER_3P_2_54MM; Voltage Rating 250V; Current Rating 3A; Manufacturer Part Number 61300311121; not fitted
J19: RPI_CMx_A; DF40HC(3.0)-100DS-0.4V; Current Rating 0.5A; Voltage Rating 150V; Manufacturer Part Number DF40HC(3.0)-100DS-0.4V(58)
Q19, Q20, Q21, Q22, Q26: SSM3K56FS,LF; SC-75; Manufacturer Part Number SSM3K56FS,LF
R19, R116: 10K; RES_0402; Tolerance 1%; Manufacturer Part Number RC0402FR-0710KL
R26: 100R; RES_0402; Tolerance 1%; Manufacturer Part Number RC0402FR-07100RL
R83, R127: 4K7; RES_0402; Tolerance 1%; Manufacturer Part Number RC0402FR-074K7L; not fitted
R115, R117, R118, R125, R126, R128, R137, R139, R140, R141, R145, R154, R155, R161, R171: 22R; RES_0402; Tolerance 1%; Manufacturer Part Number RC0402FR-0722RL
R138, R144: 10K; RES_0402; Tolerance 1%; Manufacturer Part Number RC0402FR-0710KL; not fitted
R151: 0R; RES_0402; Tolerance 1%; Manufacturer Part Number RC0402FR-071KL; not fitted
R152: 0R; RES_0402; Tolerance 1%; Manufacturer Part Number RC0402FR-071KL
R158: 30K1; RES_0402; Tolerance 1%; Manufacturer Part Number RC0402FR-0730K1L
R175: 22R; RES_0402; Tolerance 1%; Manufacturer Part Number RC0402FR-0722RL; not fitted
U19: SN74LVC1G125DBVR; SOT-23-5; Supply Voltage 1.65V ~ 5.5V; Manufacturer Part Number SN74LVC1G125DBVR
U21: MCP7940NT-I/MS; MSOP-8; Supply Voltage 1.8V ~ 5.5V; Manufacturer Part Number MCP7940NT-I/MS
Y2: 32.768kHz; 2-SMD_3_2mmx1_5mm; Tolerance ±20ppm; Manufacturer Part Number ABS07-32.768KHZ-7-T

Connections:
1V8_CMx: C76.2, C111.2, J19.88 (CM4_1V8_OUT), J19.90 (CM4_1V8_OUT)
3V3: C107.1, D16.2 (A), R19.2, R83.2, R127.2, R138.2, R144.2, R151.2, U21.8 (VDD); also elsewhere on the board
3V3_CMx: C77.2, C102.2, C109.2, J19.84 (CM4_3V3_OUT), J19.86 (CM4_3V3_OUT), R152.2, U19.5 (VCC); also elsewhere on the board
5V0: C67.2, C68.2, C74.2, C78.2, C108.2, C113.2, J19.77 (+5V), J19.79 (+5V), J19.81 (+5V), J19.83 (+5V), J19.85 (+5V), J19.87 (+5V); also elsewhere on the board
/BL_PWM: R118.2; also elsewhere on the board
/CM5_CONN_A/BT_DIS_GPIO8: C101.2, Q20.1 (G), R145.1
/CM5_CONN_A/CM5_RXD0: J17.1, J19.51 (GPIO15), R138.1
/CM5_CONN_A/CM5_TXD0: J17.3, R126.2
/CM5_CONN_A/EXT_~RST: R155.2; also elsewhere on the board
/CM5_CONN_A/FAN_PWM: R117.2
/CM5_CONN_A/FAN_TACH: J19.16 (ETH_SYNC_IN/FAN_TACH)
/CM5_CONN_A/GPIO8: J19.39 (GPIO8), R145.2
/CM5_CONN_A/GPIO10: J19.44 (GPIO10), R161.1
/CM5_CONN_A/GPIO11: J19.38 (GPIO11), R140.2
/CM5_CONN_A/GPIO12: J19.31 (GPIO12), R118.1
/CM5_CONN_A/GPIO14: J19.55 (GPIO14), R126.1
/CM5_CONN_A/GPIO18: J19.49 (GPIO18), R125.1
/CM5_CONN_A/GPIO19: J19.26 (GPIO19), R141.1
/CM5_CONN_A/GPIO21: J19.25 (GPIO21), R115.1
/CM5_CONN_A/GPIO23: J19.47 (GPIO23), R128.1
/CM5_CONN_A/GPIO25: J19.41 (GPIO25), R175.2
/CM5_CONN_A/GPIO26: J19.24 (GPIO26), R171.1
/CM5_CONN_A/GPIO35: J19.100 (~EXTRST/GPIO35), R154.2
/CM5_CONN_A/GPIO_VREF: J19.78 (GPIO_VREF), R151.1, R152.1
/CM5_CONN_A/I2S_COFS: R141.2; also elsewhere on the board
/CM5_CONN_A/I2S_DIN: J19.27 (GPIO20), R116.2; also elsewhere on the board
/CM5_CONN_A/I2S_DOUT: R115.2; also elsewhere on the board
/CM5_CONN_A/I2S_SCLK: R125.2
/CM5_CONN_A/PPS_RTC: J19.40 (GPIO9), R19.1, U21.7 (MFP)
/CM5_CONN_A/RP2350_BOOT_GPIO10: C114.2, Q22.1 (G), R161.2
/CM5_CONN_A/RP2350_SW_RESET: R171.2; also elsewhere on the board
/CM5_CONN_A/SDIO_CLK: J19.57 (SD_CLK); also elsewhere on the board
/CM5_CONN_A/SDIO_CMD: J19.62 (SD_CMD); also elsewhere on the board
/CM5_CONN_A/SDIO_D0: J19.63 (SD_DAT0); also elsewhere on the board
/CM5_CONN_A/SDIO_D1: J19.67 (SD_DAT1); also elsewhere on the board
/CM5_CONN_A/SDIO_D2: J19.69 (SD_DAT2); also elsewhere on the board
/CM5_CONN_A/SDIO_D3: J19.61 (SD_DAT3); also elsewhere on the board
/CM5_CONN_A/SD_PWR_ON: R137.2; also elsewhere on the board
/CM5_CONN_A/SHDN_GPIO23: C121.2, Q26.1 (G), R128.2
/CM5_CONN_A/WL_DIS_GPIO11: C106.2, Q19.1 (G), R140.1
/CM5_CONN_A/~BAT_CHRG_INT: J19.30 (GPIO6), R144.1; also elsewhere on the board
/CM5_CONN_A/~BT_DIS: J19.91 (~BT_DIS), Q20.3 (D)
/CM5_CONN_A/~RP2350_USB_BOOT: R26.1; also elsewhere on the board
/CM5_CONN_A/~RPIBOOT: J19.93 (~RPIBOOT), Q21.3 (D)
/CM5_CONN_A/~RPI_LED_ACT: J19.21 (~PI_LED_ACT); also elsewhere on the board
/CM5_CONN_A/~RPI_LED_PWR: J19.95 (~PI_LED_PWR); also elsewhere on the board
/CM5_CONN_A/~VOL_DOWN: J19.29 (GPIO16); also elsewhere on the board
/CM5_CONN_A/~VOL_UP: J19.28 (GPIO13); also elsewhere on the board
/CM5_CONN_A/~WL_DIS: J19.89 (~WL_DIS), Q19.3 (D)
/CM5_CONN_B/USB_PROG_OTG_ID: R139.2; also elsewhere on the board
/I2C2.I2C_SCL: J19.34 (GPIO5), R127.1, U21.6 (SCL); also elsewhere on the board
/I2C2.I2C_SDA: J19.54 (GPIO4), R83.1, U21.5 (SDA); also elsewhere on the board
/TYPE C CHARGER/~BAT_CHRG_EN: R175.1; also elsewhere on the board
/TYPE C CHARGER/~BAT_CHRG_PG: J19.46 (GPIO22); also elsewhere on the board
GND: C67.1, C68.1, C74.1, C76.1, C77.1, C78.1, C100.1, C101.1, C102.1, C104.2, C105.2, C106.1, C107.2, C108.1, C109.1, C111.1, C113.1, C114.1, C121.1, J7.2, J17.2, J19.1 (GND), J19.2 (GND), J19.7 (GND), J19.8 (GND), J19.13 (GND), J19.14 (GND), J19.22 (GND), J19.23 (GND), J19.32 (GND), J19.33 (GND), J19.42 (GND), J19.43 (GND), J19.52 (GND), J19.53 (GND), J19.59 (GND), J19.60 (GND), J19.65 (GND), J19.66 (GND), J19.71 (GND), J19.74 (GND), J19.98 (GND), Q19.2 (S), Q20.2 (S), Q21.2 (S), Q22.2 (S), Q26.2 (S), R116.1, U19.1 (~OE), U19.3 (GND), U21.4 (GND); also elsewhere on the board
unnamed: D16.1 (K), R158.2
unnamed: J19.92 (RUN_PG/PWR_BTN), Q26.3 (D)
unnamed: J19.75 (SD_PWR_ON), R137.1
unnamed: J19.19 (~ETH_LED1/FAN_PWM), R117.1
unnamed: C100.2, Q21.1 (G), R139.1
unnamed: Q22.3 (D), R26.2
unnamed: R154.1, U19.2 (A)
unnamed: R155.1, U19.4 (Y)
unnamed: J7.1, R158.1, U21.3 (VBAT)
unnamed: C104.1, U21.1 (X1), Y2.2 (XO)
unnamed: C105.1, U21.2 (X2), Y2.1 (XI)

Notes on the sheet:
INT 10K PU 3V3_CMx
INT 100K PU +5V
PU'd at DSI bridge
3.0V 6.8mm
10K PD @ USB MUX
Resistors are 1% 1/16W 0402 unless otherwise noted Capacitors are 10% 50V X7R 0402 unless otherwise noted
PU'd at BQ25640
INT 1K8 PU 3V3_CMx
For debug / DVT
INT 10K PU +5V

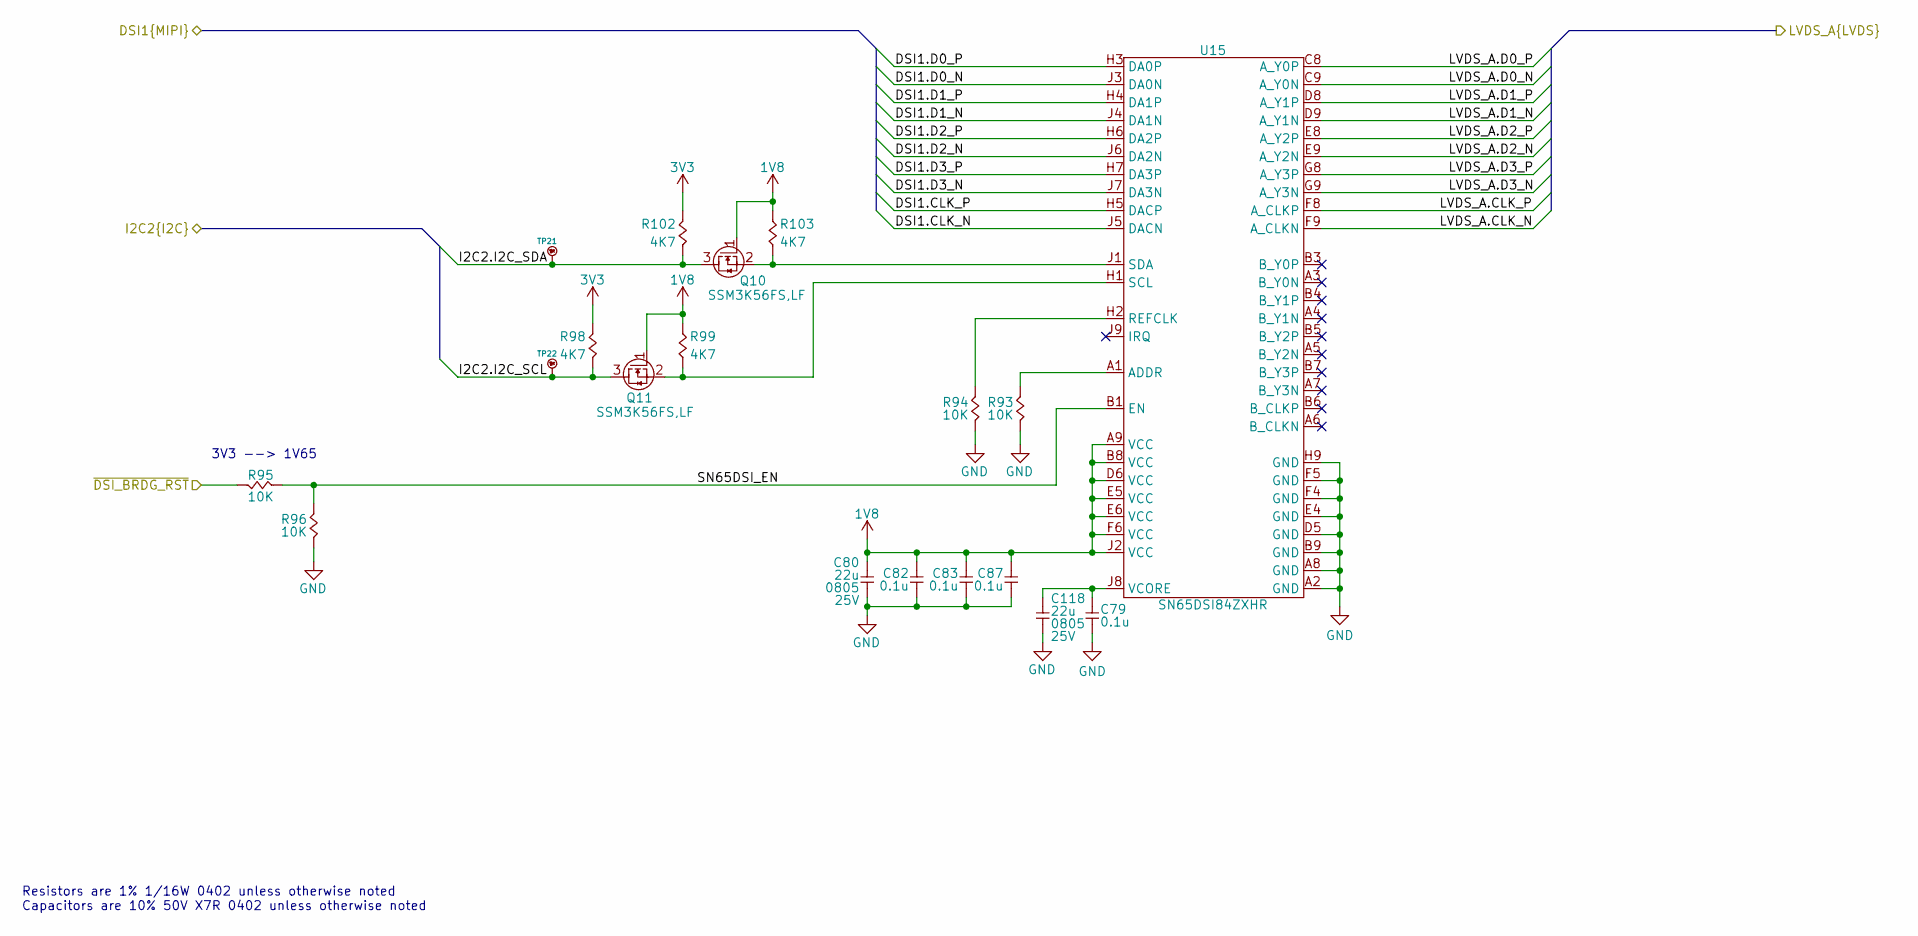
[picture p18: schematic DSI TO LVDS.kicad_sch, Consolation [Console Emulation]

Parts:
C79, C82, C83, C87: 0.1u; CAP_NONPOL_0402; Tolerance ±10%; Voltage Rating 50V; Manufacturer Part Number GRM155R71H104KE14D
C80, C118: 22u; CAP_NONPOL_0805; Tolerance ±20%; Voltage Rating 25V; Manufacturer Part Number CL21A226MAYNNNE
Q10, Q11: SSM3K56FS,LF; SC-75; Manufacturer Part Number SSM3K56FS,LF
R93, R94, R95, R96: 10K; RES_0402; Tolerance 1%; Manufacturer Part Number RC0402FR-0710KL
R98, R99, R102, R103: 4K7; RES_0402; Tolerance 1%; Manufacturer Part Number RC0402FR-074K7L
TP21, TP22: 75 mils; SMT_TP_75_MILS; Manufacturer Part Number NA
U15: SN65DSI84ZXHR; NFBGA-64; Supply Voltage 1.65V ~ 1.95V; Manufacturer Part Number SN65DSI84ZXHR

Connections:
1V8: C80.2, C82.2, C83.2, C87.2, Q10.1 (G), Q11.1 (G), R99.2, R103.2, U15.A9 (VCC), U15.B8 (VCC), U15.D6 (VCC), U15.E5 (VCC), U15.E6 (VCC), U15.F6 (VCC), U15.J2 (VCC); also elsewhere on the board
3V3: R98.2, R102.2; also elsewhere on the board
/CM5_CONN_B/DSI1.CLK_N: U15.J5 (DACN); also elsewhere on the board
/CM5_CONN_B/DSI1.CLK_P: U15.H5 (DACP); also elsewhere on the board
/CM5_CONN_B/DSI1.D0_N: U15.J3 (DA0N); also elsewhere on the board
/CM5_CONN_B/DSI1.D0_P: U15.H3 (DA0P); also elsewhere on the board
/CM5_CONN_B/DSI1.D1_N: U15.J4 (DA1N); also elsewhere on the board
/CM5_CONN_B/DSI1.D1_P: U15.H4 (DA1P); also elsewhere on the board
/CM5_CONN_B/DSI1.D2_N: U15.J6 (DA2N); also elsewhere on the board
/CM5_CONN_B/DSI1.D2_P: U15.H6 (DA2P); also elsewhere on the board
/CM5_CONN_B/DSI1.D3_N: U15.J7 (DA3N); also elsewhere on the board
/CM5_CONN_B/DSI1.D3_P: U15.H7 (DA3P); also elsewhere on the board
/DSI TO LVDS/LVDS_A.CLK_N: U15.F9 (A_CLKN); also elsewhere on the board
/DSI TO LVDS/LVDS_A.CLK_P: U15.F8 (A_CLKP); also elsewhere on the board
/DSI TO LVDS/LVDS_A.D0_N: U15.C9 (A_Y0N); also elsewhere on the board
/DSI TO LVDS/LVDS_A.D0_P: U15.C8 (A_Y0P); also elsewhere on the board
/DSI TO LVDS/LVDS_A.D1_N: U15.D9 (A_Y1N); also elsewhere on the board
/DSI TO LVDS/LVDS_A.D1_P: U15.D8 (A_Y1P); also elsewhere on the board
/DSI TO LVDS/LVDS_A.D2_N: U15.E9 (A_Y2N); also elsewhere on the board
/DSI TO LVDS/LVDS_A.D2_P: U15.E8 (A_Y2P); also elsewhere on the board
/DSI TO LVDS/LVDS_A.D3_N: U15.G9 (A_Y3N); also elsewhere on the board
/DSI TO LVDS/LVDS_A.D3_P: U15.G8 (A_Y3P); also elsewhere on the board
/DSI TO LVDS/SN65DSI_EN: R95.1, R96.2, U15.B1 (EN)
/I2C2.I2C_SCL: Q11.3 (D), R98.1, TP22.1; also elsewhere on the board
/I2C2.I2C_SDA: Q10.3 (D), R102.1, TP21.1; also elsewhere on the board
/~DSI_BRDG_RST: R95.2; also elsewhere on the board
GND: C79.1, C80.1, C82.1, C83.1, C87.1, C118.1, R93.1, R94.1, R96.1, U15.A2 (GND), U15.A8 (GND), U15.B9 (GND), U15.D5 (GND), U15.E4 (GND), U15.F4 (GND), U15.F5 (GND), U15.H9 (GND); also elsewhere on the board
unnamed: Q10.2 (S), R103.1, U15.J1 (SDA)
unnamed: Q11.2 (S), R99.1, U15.H1 (SCL)
unnamed: R93.2, U15.A1 (ADDR)
unnamed: R94.2, U15.H2 (REFCLK)
unnamed: C79.2, C118.2, U15.J8 (VCORE)

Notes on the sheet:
3V3 --> 1V65
Resistors are 1% 1/16W 0402 unless otherwise noted Capacitors are 10% 50V X7R 0402 unless otherwise noted

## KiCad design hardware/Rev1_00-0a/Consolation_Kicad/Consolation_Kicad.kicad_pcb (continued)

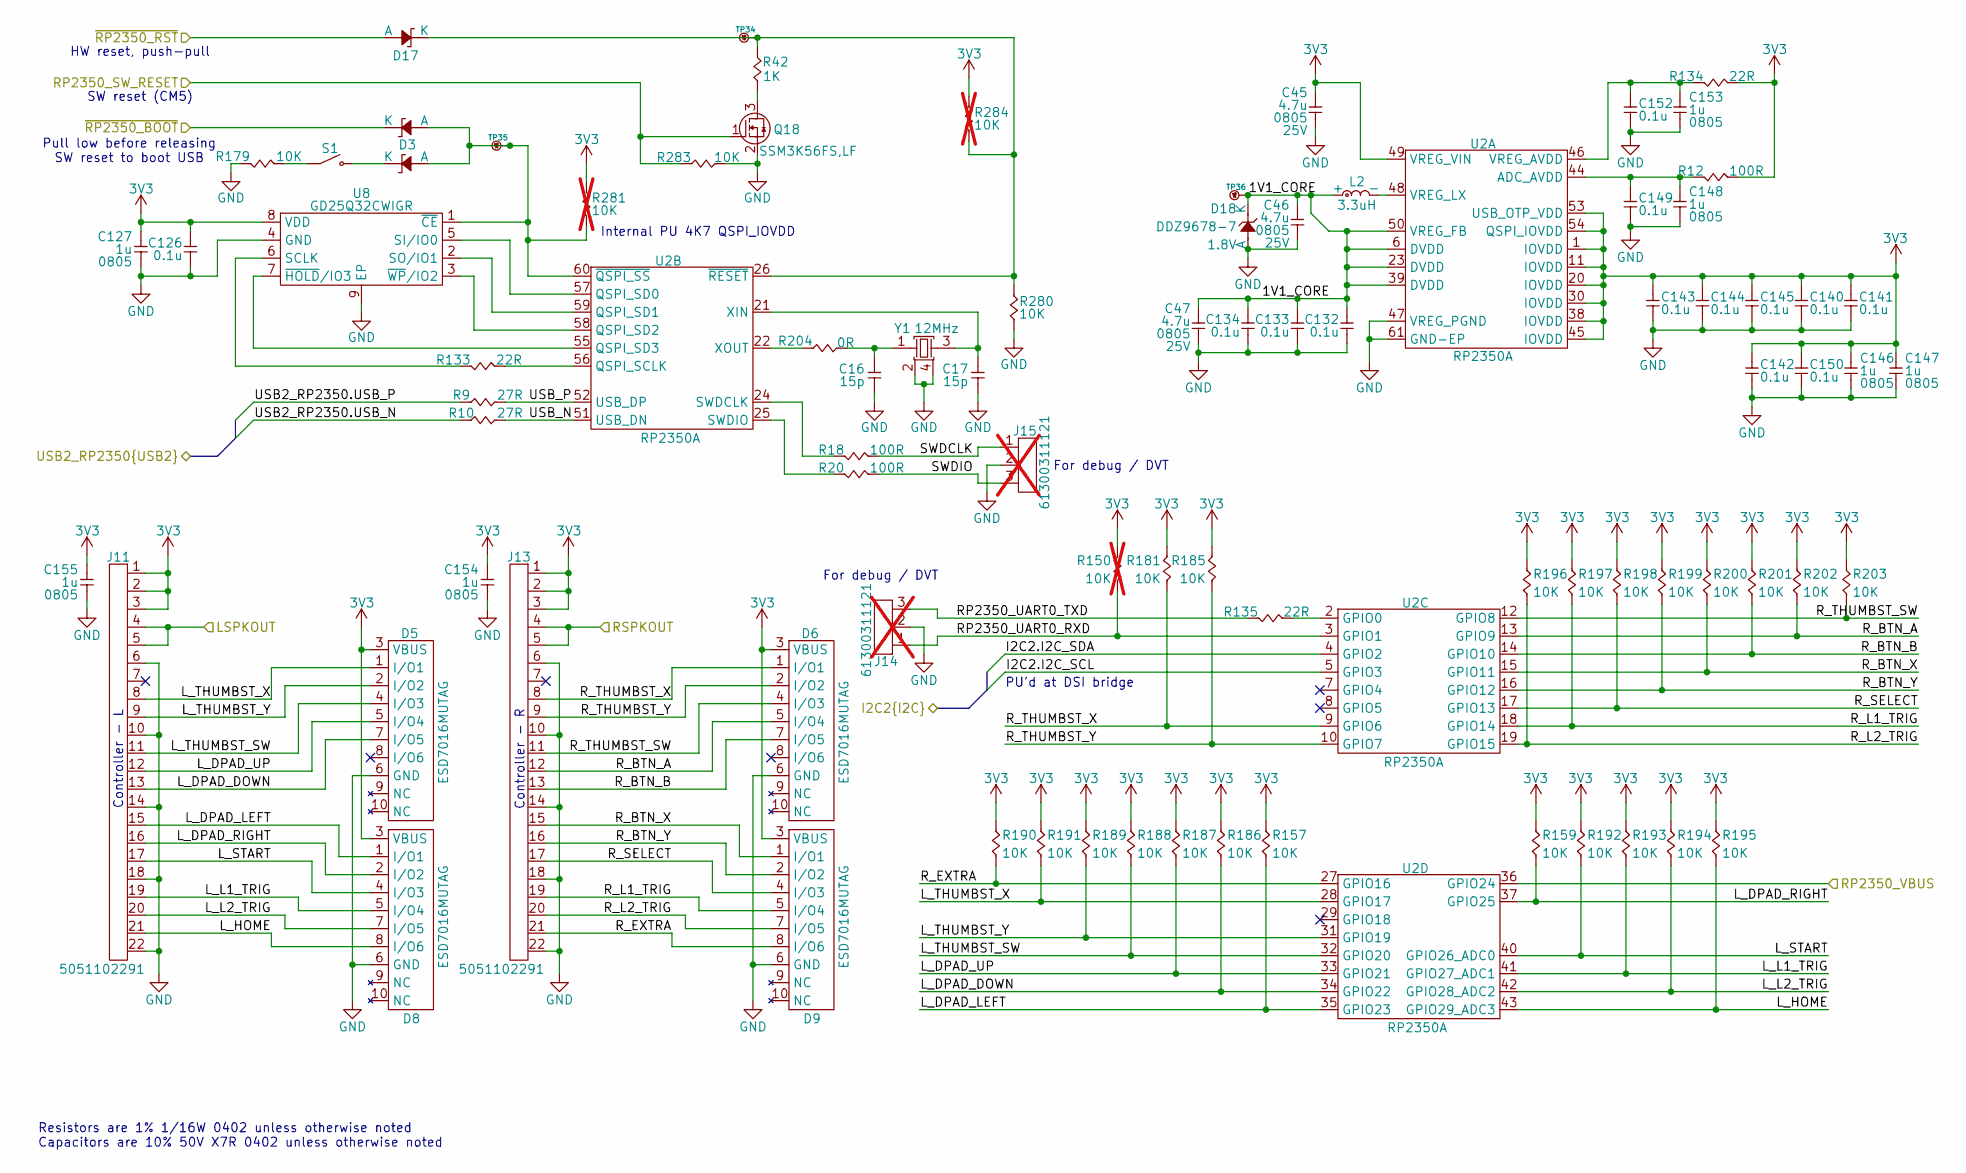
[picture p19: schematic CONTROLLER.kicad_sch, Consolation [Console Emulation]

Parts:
C16, C17: 15p; CAP_NONPOL_0402; Tolerance ±5%; Voltage Rating 50V; Manufacturer Part Number GRM1555C1H150JA01D
C45, C46, C47: 4.7u; CAP_NONPOL_0805; Tolerance ±10%; Voltage Rating 25V; Manufacturer Part Number TMK212AB7475KG-T
C126, C132, C133, C134, C140, C141, C142, C143, C144, C145, C149, C150, C152: 0.1u; CAP_NONPOL_0402; Tolerance ±10%; Voltage Rating 50V; Manufacturer Part Number GRM155R71H104KE14D
C127, C146, C147, C148, C153, C154, C155: 1u; CAP_NONPOL_0805; Tolerance ±10%; Voltage Rating 50V; Manufacturer Part Number CC0805KKX7R9BB105
D2, D3, D17: BAT42WS-TP; SOD-323; Tolerance NA; Manufacturer Part Number BAT42WS-TP
D5, D6, D8, D9: ESD7016MUTAG; UDFN8; Manufacturer Part Number ESD7016MUTAG
D18: DDZ9678-7; SOD-123; Tolerance ±5%; Manufacturer Part Number DDZ9678-7
J11, J13: 5051102291; Current Rating 0.5A; Voltage Rating 50V; Manufacturer Part Number 5051102291
J14, J15: 61300311121; HEADER_3P_2_54MM; Voltage Rating 250V; Current Rating 3A; Manufacturer Part Number 61300311121; not fitted
L2: AOTA-B201610S3R3-101-T; Tolerance ±20%; Manufacturer Part Number AOTA-B201610S3R3-101-T
Q18: SSM3K56FS,LF; SC-75; Manufacturer Part Number SSM3K56FS,LF
R9, R10: 27R; RES_0402; Tolerance 1%; Manufacturer Part Number RC0402FR-0727RL
R12, R18, R20: 100R; RES_0402; Tolerance 1%; Manufacturer Part Number RC0402FR-07100RL
R42: 1K; RES_0402; Tolerance 1%; Manufacturer Part Number RC0402FR-071KL
R133, R134, R135: 22R; RES_0402; Tolerance 1%; Manufacturer Part Number RC0402FR-0722RL
R150, R281, R284: 10K; RES_0402; Tolerance 1%; Manufacturer Part Number RC0402FR-0710KL; not fitted
R157, R159, R179, R181, R185, R186, R187, R188, R189, R190, R191, R192, R193, R194, R195, R196, R197, R198, R199, R200, R201, R202, R203, R280, R283: 10K; RES_0402; Tolerance 1%; Manufacturer Part Number RC0402FR-0710KL
R204: 0R; RES_0402; Tolerance 1%; Manufacturer Part Number RC0402FR-071KL
S1: KSR233G LFG; Y35A23310FPLFG; Manufacturer Part Number KSR233G LFG
TP34, TP35, TP36: 75 mils; SMT_TP_75_MILS; Manufacturer Part Number NA
U2: RP2350A; 60-QFN-EP(7x7mm); Supply Voltage 1.8V ~ 5.5V; Manufacturer Part Number SC1509-A4
U8: GD25Q32CWIGR; WSON-8-EP; Supply Voltage 2.7V ~ 3.6V; Manufacturer Part Number GD25Q32CWIGR
Y1: 12MHz 10pF; 4-SMD_3_2mmx2_5mm; Tolerance ±30ppm; Manufacturer Part Number ABM8-272-T3

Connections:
3V3: C45.1, C126.2, C127.2, C140.2, C141.2, C142.2, C143.2, C144.2, C145.2, C146.2, C147.2, C150.2, C154.2, C155.2, D5.3 (VBUS), D6.3 (VBUS), D8.3 (VBUS), D9.3 (VBUS), J11.1, J11.2, J11.3, J13.1, J13.2, J13.3, R12.1, R134.1, R150.2, R157.2, R159.2, R181.2, R185.2, R186.2, R187.2, R188.2, R189.2, R190.2, R191.2, R192.2, R193.2, R194.2, R195.2, R196.2, R197.2, R198.2, R199.2, R200.2, R201.2, R202.2, R203.2, R281.2, R284.2, U2.1 (IOVDD), U2.11 (IOVDD), U2.20 (IOVDD), U2.30 (IOVDD), U2.38 (IOVDD), U2.45 (IOVDD), U2.49 (VREG_VIN), U2.53 (USB_OTP_VDD), U2.54 (QSPI_IOVDD), U8.8 (VDD); also elsewhere on the board
/CM5_CONN_A/RP2350_SW_RESET: Q18.1 (G), R283.2; also elsewhere on the board
/CM5_CONN_A/~RP2350_USB_BOOT: D2.1 (K); also elsewhere on the board
/CM5_CONN_B/RP2350_VBUS: U2.36 (GPIO24); also elsewhere on the board
/CM5_CONN_B/USB2_RP2350.USB_N: R10.1; also elsewhere on the board
/CM5_CONN_B/USB2_RP2350.USB_P: R9.1; also elsewhere on the board
/CODEC/LSPKOUT: J11.4, J11.5; also elsewhere on the board
/CODEC/RSPKOUT: J13.4, J13.5; also elsewhere on the board
/CONTROLLER/1V1_CORE: C46.1, C47.1, C132.2, C133.2, C134.2, D18.1 (K), L2.1 (+), TP36.1, U2.6 (DVDD), U2.23 (DVDD), U2.39 (DVDD), U2.50 (VREG_FB)
/CONTROLLER/L_DPAD_DOWN: D5.7 (I/O5), J11.13, R186.1, U2.34 (GPIO22)
/CONTROLLER/L_DPAD_LEFT: D8.1 (I/O1), J11.15, R157.1, U2.35 (GPIO23)
/CONTROLLER/L_DPAD_RIGHT: D8.2 (I/O2), J11.16, R159.1, U2.37 (GPIO25)
/CONTROLLER/L_DPAD_UP: D5.5 (I/O4), J11.12, R187.1, U2.33 (GPIO21)
/CONTROLLER/L_HOME: D8.8 (I/O6), J11.21, R195.1, U2.43 (GPIO29_ADC3)
/CONTROLLER/L_L1_TRIG: D8.5 (I/O4), J11.19, R193.1, U2.41 (GPIO27_ADC1)
/CONTROLLER/L_L2_TRIG: D8.7 (I/O5), J11.20, R194.1, U2.42 (GPIO28_ADC2)
/CONTROLLER/L_START: D8.4 (I/O3), J11.17, R192.1, U2.40 (GPIO26_ADC0)
/CONTROLLER/L_THUMBST_SW: D5.4 (I/O3), J11.11, R188.1, U2.32 (GPIO20)
/CONTROLLER/L_THUMBST_X: D5.1 (I/O1), J11.8, R191.1, U2.28 (GPIO17)
/CONTROLLER/L_THUMBST_Y: D5.2 (I/O2), J11.9, R189.1, U2.31 (GPIO19)
/CONTROLLER/RP2350_UART0_RXD: J14.1, R150.1, U2.3 (GPIO1)
/CONTROLLER/RP2350_UART0_TXD: J14.3, R135.2
/CONTROLLER/R_BTN_A: D6.5 (I/O4), J13.12, R202.1, U2.13 (GPIO9)
/CONTROLLER/R_BTN_B: D6.7 (I/O5), J13.13, R201.1, U2.14 (GPIO10)
/CONTROLLER/R_BTN_X: D9.1 (I/O1), J13.15, R200.1, U2.15 (GPIO11)
/CONTROLLER/R_BTN_Y: D9.2 (I/O2), J13.16, R199.1, U2.16 (GPIO12)
/CONTROLLER/R_EXTRA: D9.8 (I/O6), J13.21, R190.1, U2.27 (GPIO16)
/CONTROLLER/R_L1_TRIG: D9.5 (I/O4), J13.19, R197.1, U2.18 (GPIO14)
/CONTROLLER/R_L2_TRIG: D9.7 (I/O5), J13.20, R196.1, U2.19 (GPIO15)
/CONTROLLER/R_SELECT: D9.4 (I/O3), J13.17, R198.1, U2.17 (GPIO13)
/CONTROLLER/R_THUMBST_SW: D6.4 (I/O3), J13.11, R203.1, U2.12 (GPIO8)
/CONTROLLER/R_THUMBST_X: D6.1 (I/O1), J13.8, R181.1, U2.9 (GPIO6)
/CONTROLLER/R_THUMBST_Y: D6.2 (I/O2), J13.9, R185.1, U2.10 (GPIO7)
/CONTROLLER/SWDCLK: J15.1, R18.1
/CONTROLLER/SWDIO: J15.3, R20.1
/CONTROLLER/USB_N: R10.2, U2.51 (USB_DN)
/CONTROLLER/USB_P: R9.2, U2.52 (USB_DP)
/I2C2.I2C_SCL: U2.5 (GPIO3); also elsewhere on the board
/I2C2.I2C_SDA: U2.4 (GPIO2); also elsewhere on the board
/~RP2350_RST: D17.2 (A); also elsewhere on the board
GND: C16.1, C17.1, C45.2, C46.2, C47.2, C126.1, C127.1, C132.1, C133.1, C134.1, C140.1, C141.1, C142.1, C143.1, C144.1, C145.1, C146.1, C147.1, C148.1, C149.1, C150.1, C152.1, C153.1, C154.1, C155.1, D5.6 (GND), D6.6 (GND), D8.6 (GND), D9.6 (GND), D18.2 (A), J11.6, J11.10, J11.14, J11.18, J11.22, J13.6, J13.10, J13.14, J13.18, J13.22, J14.2, J15.2, Q18.2 (S), R179.1, R280.1, R283.1, U2.47 (VREG_PGND), U2.61 (GND-EP), U8.4 (GND), U8.9 (EP), Y1.2 (GND), Y1.4 (GND); also elsewhere on the board
unnamed: D2.2 (A), D3.2 (A), R281.1, TP35.1, U2.60 (~QSPI_SS), U8.1 (~CE)
unnamed: D3.1 (K), S1.2
unnamed: D17.1 (K), R42.2, R280.2, R284.1, TP34.1, U2.26 (~RESET)
unnamed: L2.2 (-), U2.48 (VREG_LX)
unnamed: Q18.3 (D), R42.1
unnamed: R179.2, S1.1
unnamed: C148.2, C149.2, R12.2, U2.44 (ADC_AVDD)
unnamed: C152.2, C153.2, R134.2, U2.46 (VREG_AVDD)
unnamed: R133.1, U2.56 (QSPI_SCLK)
unnamed: U2.57 (QSPI_SD0), U8.5 (SI/IO0)
unnamed: U2.59 (QSPI_SD1), U8.2 (SO/IO1)
unnamed: U2.58 (QSPI_SD2), U8.3 (~WP/IO2)
unnamed: U2.55 (QSPI_SD3), U8.7 (~HOLD/IO3)
unnamed: R18.2, U2.24 (SWDCLK)
unnamed: R20.2, U2.25 (SWDIO)
unnamed: C17.2, U2.21 (XIN), Y1.3 (XO)
unnamed: R204.1, U2.22 (XOUT)
unnamed: R135.1, U2.2 (GPIO0)
unnamed: R133.2, U8.6 (SCLK)
unnamed: C16.2, R204.2, Y1.1 (XI)

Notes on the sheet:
PU'd at DSI bridge
Controller - L
SW reset (CM5)
For debug / DVT
Resistors are 1% 1/16W 0402 unless otherwise noted Capacitors are 10% 50V X7R 0402 unless otherwise noted
Controller - R
HW reset, push-pull
Internal PU 4K7 QSPI_IOVDD
Pull low before releasing SW reset to boot USB

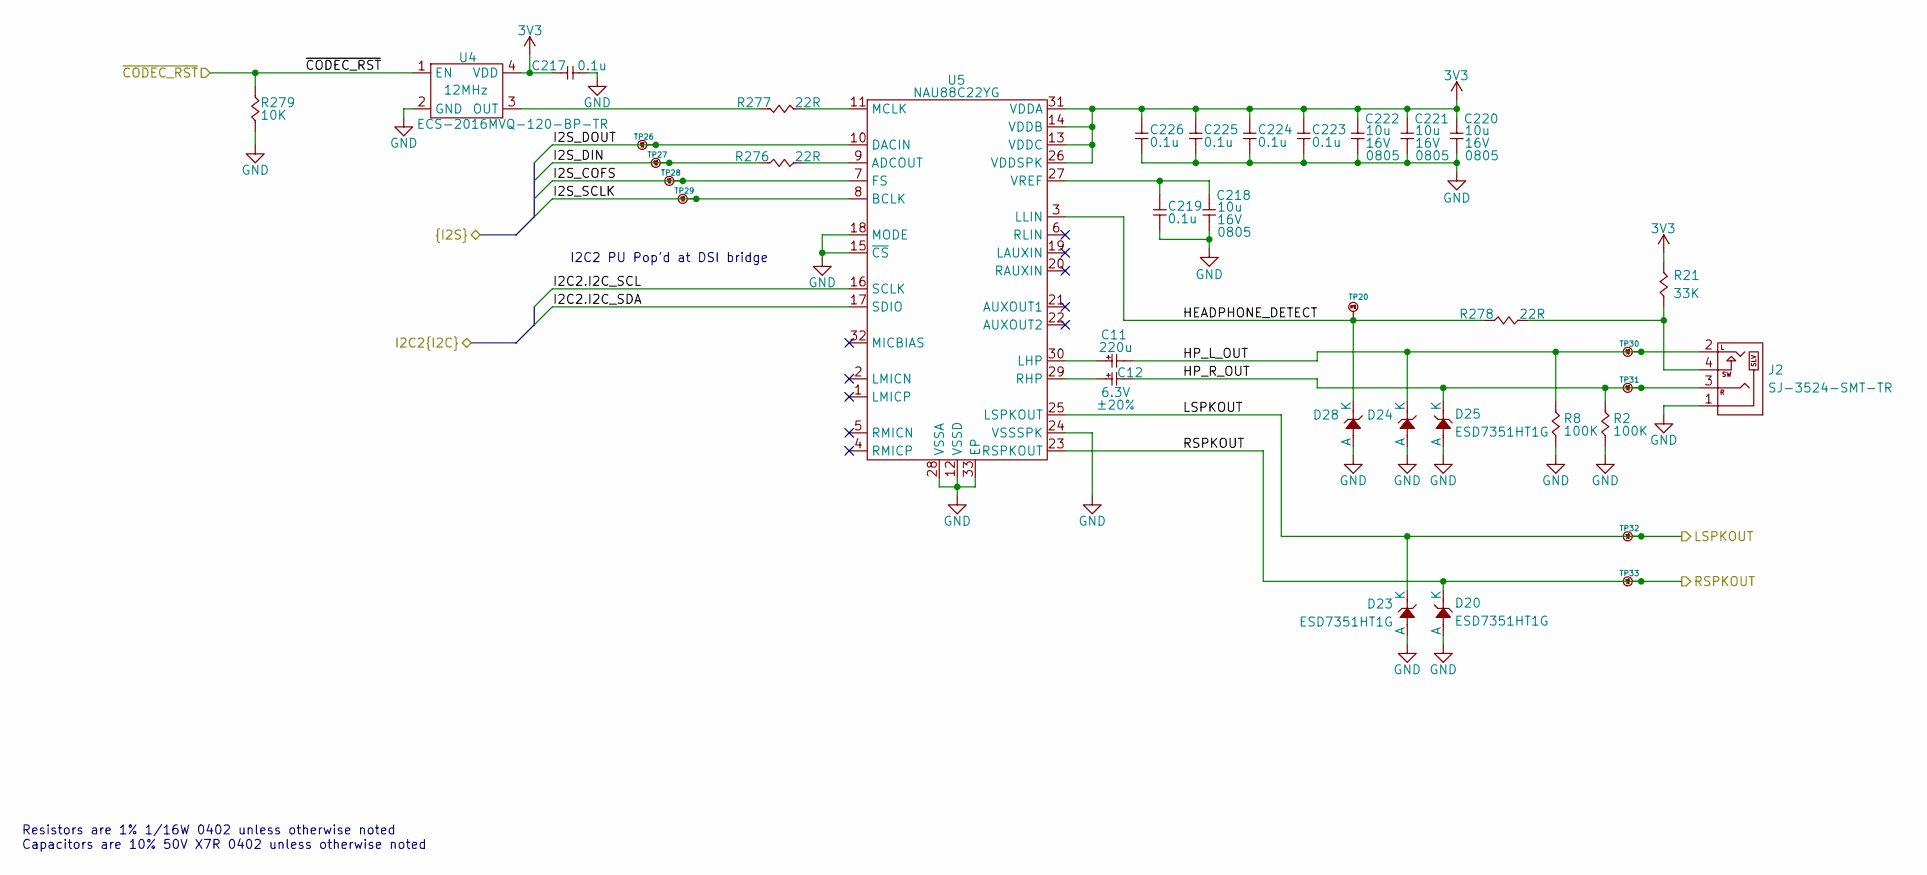
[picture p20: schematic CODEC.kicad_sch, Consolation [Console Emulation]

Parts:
C11, C12: 220u; CAP_ALU_6_3mm_6_10mm; Tolerance ±20%; Voltage Rating 6.3V; Manufacturer Part Number UUD0J221MCL1GS
C217, C219, C223, C224, C225, C226: 0.1u; CAP_NONPOL_0402; Tolerance ±10%; Voltage Rating 50V; Manufacturer Part Number GRM155R71H104KE14D
C218, C220, C221, C222: 10u; CAP_NONPOL_0805; Tolerance ±10%; Voltage Rating 16V; Manufacturer Part Number CL21A106KOQNNNE
D20, D23, D24, D25, D28: ESD7351HT1G; SOD-323; Manufacturer Part Number ESD7351HT1G
J2: SJ-3524-SMT-TR; SJ-352X-SMT; Voltage Rating 12V; Current Rating 1A; Manufacturer Part Number SJ-3524-SMT-TR
R2, R8: 100K; RES_0402; Tolerance 1%; Manufacturer Part Number RC0402FR-07100KL
R21: 33K; RES_0402; Tolerance 1%; Manufacturer Part Number RC0402FR-0733KL
R276, R277, R278: 22R; RES_0402; Tolerance 1%; Manufacturer Part Number RC0402FR-0722RL
R279: 10K; RES_0402; Tolerance 1%; Manufacturer Part Number RC0402FR-0710KL
TP20, TP26, TP27, TP28, TP29, TP30, TP31, TP32, TP33: 75 mils; SMT_TP_75_MILS; Manufacturer Part Number NA
U4: ECS-2016MVQ-120-BP-TR; 4-SMD_2mmx1_6mm; Tolerance ±50ppm; Supply Voltage 3.3V; Manufacturer Part Number ECS-2016MVQ-120-BP-TR
U5: NAU88C22YG; 32-QFN-EP; Supply Voltage 1.65V ~ 3.6V; Manufacturer Part Number NAU88C22YG

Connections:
3V3: C217.2, C220.2, C221.2, C222.2, C223.2, C224.2, C225.2, C226.2, R21.2, U4.4 (VDD), U5.13 (VDDC), U5.14 (VDDB), U5.26 (VDDSPK), U5.31 (VDDA); also elsewhere on the board
/CM5_CONN_A/I2S_COFS: TP28.1, U5.7 (FS); also elsewhere on the board
/CM5_CONN_A/I2S_DIN: R276.2, TP27.1; also elsewhere on the board
/CM5_CONN_A/I2S_DOUT: TP26.1, U5.10 (DACIN); also elsewhere on the board
/CODEC/HEADPHONE_DETECT: D28.1 (K), R278.2, TP20.1, U5.3 (LLIN)
/CODEC/HP_L_OUT: C11.2, D24.1 (K), J2.2 (L), R8.2, TP30.1
/CODEC/HP_R_OUT: C12.2, D25.1 (K), J2.3 (R), R2.2, TP31.1
/CODEC/I2S_SCLK: TP29.1, U5.8 (BCLK)
/CODEC/LSPKOUT: D23.1 (K), TP32.1, U5.25 (LSPKOUT); also elsewhere on the board
/CODEC/RSPKOUT: D20.1 (K), TP33.1, U5.23 (RSPKOUT); also elsewhere on the board
/I2C2.I2C_SCL: U5.16 (SCLK); also elsewhere on the board
/I2C2.I2C_SDA: U5.17 (SDIO); also elsewhere on the board
/~CODEC_RST: R279.2, U4.1 (EN); also elsewhere on the board
GND: C217.1, C218.1, C219.1, C220.1, C221.1, C222.1, C223.1, C224.1, C225.1, C226.1, D20.2 (A), D23.2 (A), D24.2 (A), D25.2 (A), D28.2 (A), J2.1 (SLV), R2.1, R8.1, R279.1, U4.2 (GND), U5.12 (VSSD), U5.15 (~CS), U5.18 (MODE), U5.24 (VSSSPK), U5.28 (VSSA), U5.33 (EP); also elsewhere on the board
unnamed: J2.4 (SW), R21.1, R278.1
unnamed: R277.1, U4.3 (OUT)
unnamed: R276.1, U5.9 (ADCOUT)
unnamed: C11.1, U5.30 (LHP)
unnamed: R277.2, U5.11 (MCLK)
unnamed: C12.1, U5.29 (RHP)
unnamed: C218.2, C219.2, U5.27 (VREF)

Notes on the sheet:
Resistors are 1% 1/16W 0402 unless otherwise noted Capacitors are 10% 50V X7R 0402 unless otherwise noted
I2C2 PU Pop'd at DSI bridge

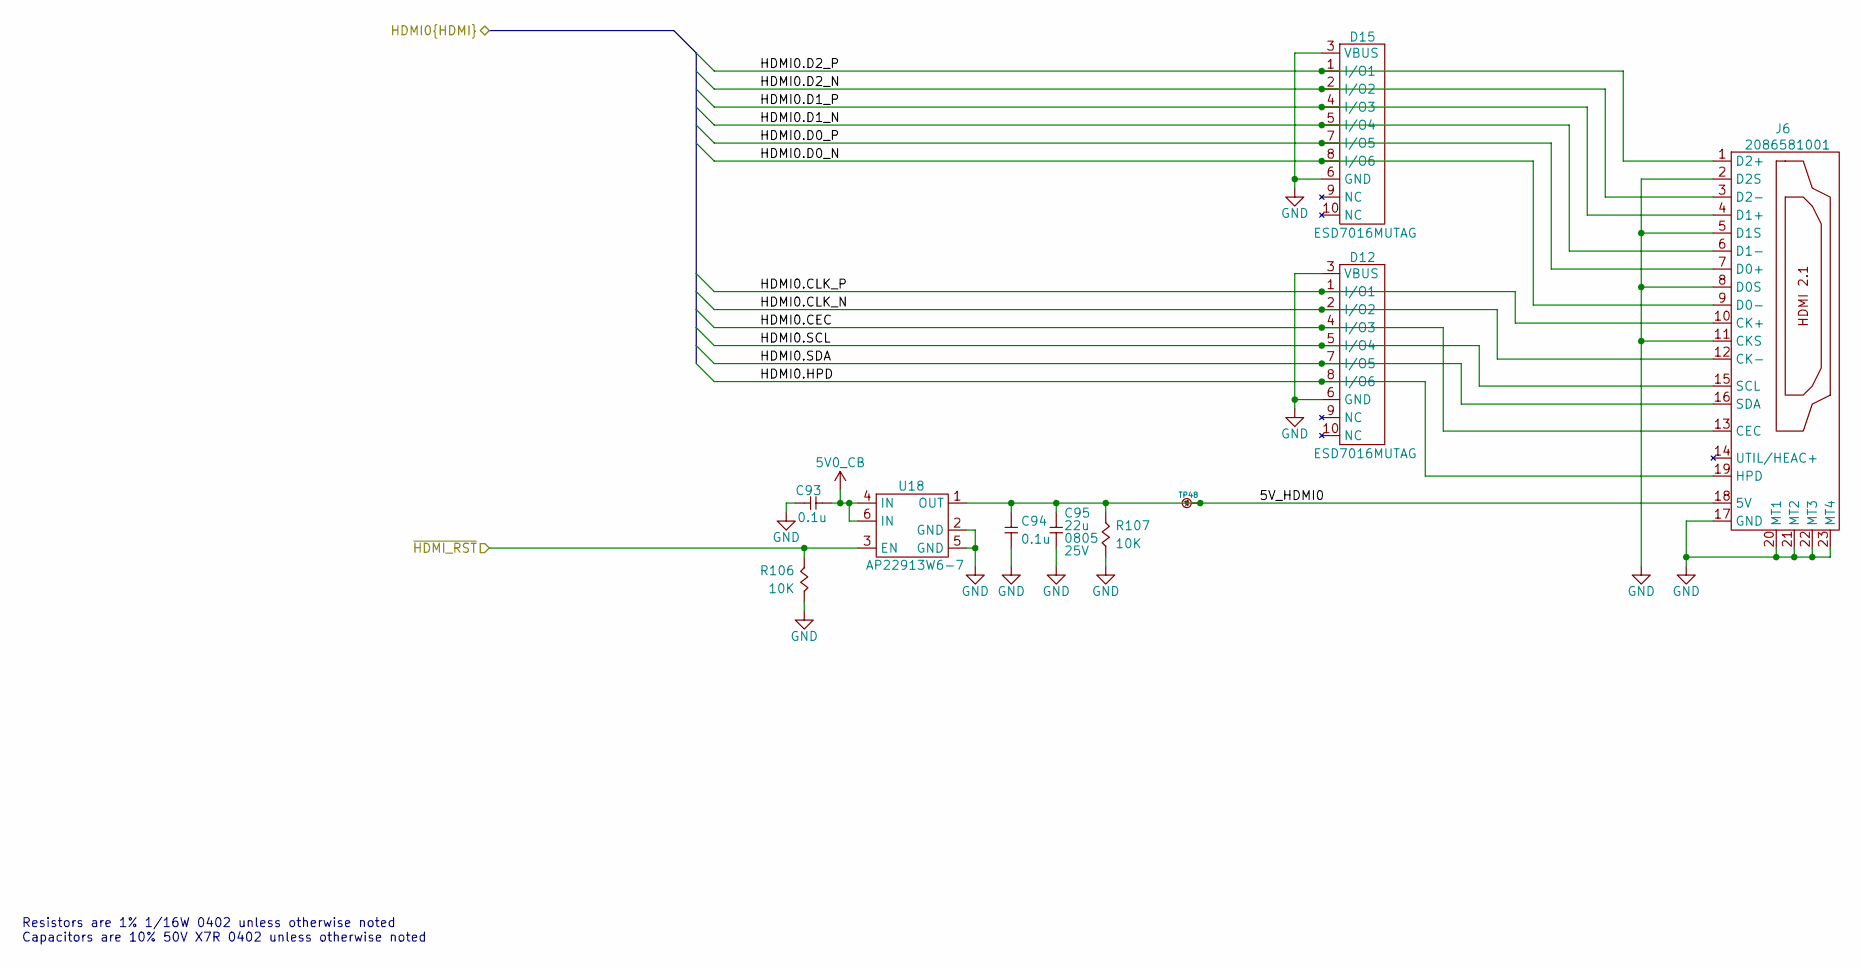
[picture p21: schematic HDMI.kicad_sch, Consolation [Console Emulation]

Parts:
C93, C94: 0.1u; CAP_NONPOL_0402; Tolerance ±10%; Voltage Rating 50V; Manufacturer Part Number GRM155R71H104KE14D
C95: 22u; CAP_NONPOL_0805; Tolerance ±20%; Voltage Rating 25V; Manufacturer Part Number CL21A226MAYNNNE
D12, D15: ESD7016MUTAG; UDFN8; Manufacturer Part Number ESD7016MUTAG
J6: 2086581001; Current Rating 0.5A; Voltage Rating 40V; Manufacturer Part Number 2086581001
R106, R107: 10K; RES_0402; Tolerance 1%; Manufacturer Part Number RC0402FR-0710KL
TP48: 75 mils; SMT_TP_75_MILS; Manufacturer Part Number NA
U18: AP22913W6-7; SOT-23-6; Load Voltage 1.5V ~ 5.5V; Manufacturer Part Number AP22913W6-7

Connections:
5V0_CB: C93.2, U18.4 (IN), U18.6 (IN)
/CM5_CONN_B/HDMI0.CEC: D12.4 (I/O3), J6.13 (CEC); also elsewhere on the board
/CM5_CONN_B/HDMI0.CLK_N: D12.2 (I/O2), J6.12 (CK-); also elsewhere on the board
/CM5_CONN_B/HDMI0.CLK_P: D12.1 (I/O1), J6.10 (CK+); also elsewhere on the board
/CM5_CONN_B/HDMI0.D0_N: D15.8 (I/O6), J6.9 (D0-); also elsewhere on the board
/CM5_CONN_B/HDMI0.D0_P: D15.7 (I/O5), J6.7 (D0+); also elsewhere on the board
/CM5_CONN_B/HDMI0.D1_N: D15.5 (I/O4), J6.6 (D1-); also elsewhere on the board
/CM5_CONN_B/HDMI0.D1_P: D15.4 (I/O3), J6.4 (D1+); also elsewhere on the board
/CM5_CONN_B/HDMI0.D2_N: D15.2 (I/O2), J6.3 (D2-); also elsewhere on the board
/CM5_CONN_B/HDMI0.D2_P: D15.1 (I/O1), J6.1 (D2+); also elsewhere on the board
/CM5_CONN_B/HDMI0.HPD: D12.8 (I/O6), J6.19 (HPD); also elsewhere on the board
/CM5_CONN_B/HDMI0.SCL: D12.5 (I/O4), J6.15 (SCL); also elsewhere on the board
/CM5_CONN_B/HDMI0.SDA: D12.7 (I/O5), J6.16 (SDA); also elsewhere on the board
/HDMI/5V_HDMI0: C94.2, C95.2, J6.18 (5V), R107.2, TP48.1, U18.1 (OUT)
/~HDMI_RST: R106.2, U18.3 (EN); also elsewhere on the board
GND: C93.1, C94.1, C95.1, D12.3 (VBUS), D12.6 (GND), D15.3 (VBUS), D15.6 (GND), J6.2 (D2S), J6.5 (D1S), J6.8 (D0S), J6.11 (CKS), J6.17 (GND), J6.20 (MT1), J6.21 (MT2), J6.22 (MT3), J6.23 (MT4), R106.1, R107.1, U18.2 (GND), U18.5 (GND); also elsewhere on the board

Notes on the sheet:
Resistors are 1% 1/16W 0402 unless otherwise noted Capacitors are 10% 50V X7R 0402 unless otherwise noted

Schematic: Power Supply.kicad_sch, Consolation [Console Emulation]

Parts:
C22: 10n; CAP_NONPOL_0402; Tolerance ±10%; Voltage Rating 50V; Manufacturer Part Number GCM155R71H103KA55D
C23, C29, C30, C31, C37: 10u; CAP_NONPOL_1210; Tolerance ±10%; Voltage Rating 50V; Manufacturer Part Number C3225X7R1H106K250AC
C26, C35, C40: 22u; CAP_NONPOL_0805; Tolerance ±20%; Voltage Rating 25V; Manufacturer Part Number CL21A226MAYNNNE
C27, C39: 10p; CAP_NONPOL_0402; Tolerance ±5%; Voltage Rating 50V; Manufacturer Part Number CC0402JRNPO9BN100
C28, C36, C42: 1u; CAP_NONPOL_0805; Tolerance ±10%; Voltage Rating 50V; Manufacturer Part Number CC0805KKX7R9BB105
C33: 100p; CAP_NONPOL_0402; Tolerance ±5%; Voltage Rating 50V; Manufacturer Part Number CC0402JRNPO9BN101
C119: 0.1u; CAP_NONPOL_0402; Tolerance ±10%; Voltage Rating 50V; Manufacturer Part Number GRM155R71H104KE14D
D7: MMSZ5226B-7-F; SOD-123; Tolerance ±5%; Manufacturer Part Number MMSZ5226B-7-F
D10: MMSZ5231B-7-F; SOD-123; Tolerance ±5%; Manufacturer Part Number MMSZ5231B-7-F
D11: DDZ9678-7; SOD-123; Tolerance ±5%; Manufacturer Part Number DDZ9678-7
L3: PA5003.102NLT; PA5003; Tolerance ±20%; Manufacturer Part Number PA5003.102NLT
L4: PA5003.471NLT; PA5003; Tolerance ±20%; Manufacturer Part Number PA5003.471NLT
Q1, Q3: SSM3K56FS,LF; SC-75; Manufacturer Part Number SSM3K56FS,LF
R1, R31, R37, R43: 100K; RES_0402; Tolerance 1%; Manufacturer Part Number RC0402FR-07100KL
R13, R14: 0R; RES_1206; Tolerance 1%; Manufacturer Part Number RC1206JR-070RL
R27: 316K; RES_0402; Tolerance 1%; Manufacturer Part Number RC0402FR-13316KL
R30: 453K; RES_0402; Tolerance 1%; Manufacturer Part Number RC0402FR-13453KL
R33: 17K8; RES_0402; Tolerance 1%; Manufacturer Part Number RC0402FR-0717K8L
R108: 4K7; RES_0402; Tolerance 1%; Manufacturer Part Number RC0402FR-074K7L
R163, R164, R166, R168: 10K; RES_0402; Tolerance 1%; Manufacturer Part Number RC0402FR-0710KL
R182: 6K04; RES_0402; Tolerance 1%; Manufacturer Part Number RC0402FR-076K04P
TP9, TP10, TP11, TP12, TP13, TP14, TP50, TP51: 75 mils; SMT_TP_75_MILS; Manufacturer Part Number NA
U7: TPS79901DRVR; WSON-6-EP; Output Voltage 1.20V ~ 6.5V; Input Voltage (Min) 2.7V; Manufacturer Part Number TPS79901DRVR
U9: TPS61230ARNSR; VQFN-7; Input Voltage (Min) 2.5V; Output Voltage 2.5V ~ 5.5V; Manufacturer Part Number TPS61230ARNSR
U10: TPS62826DMQR; VSON-HR-6; Output Voltage 0.6V ~ 4.0V; Input Voltage (Min) 2.4V; Manufacturer Part Number TPS62826DMQR

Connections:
1V8: C39.2, C40.2, C42.2, D11.1 (K), R33.2, TP13.1, U7.1 (OUT); also elsewhere on the board
3V3: C33.2, C35.2, C36.2, C37.2, C119.2, D7.1 (K), L4.2 (-), R30.2, R163.2, TP12.1, U7.4 (EN), U7.6 (IN); also elsewhere on the board
3V3_CMx: Q1.1 (G), R166.2, TP51.1; also elsewhere on the board
5V0: C26.2, C27.2, C28.2, D10.1 (K), R27.2, R108.2, R182.2, TP11.1, U9.7 (VOUT); also elsewhere on the board
/Power Supply/VSYS: R13.1, R14.1; also elsewhere on the board
/Power Supply/~CM5_PWG: Q1.3 (D), Q3.1 (G), R43.2, R108.1, TP50.1
GND: C23.1, C26.1, C28.1, C29.1, C30.1, C31.1, C35.1, C36.1, C37.1, C40.1, C42.1, C119.1, D7.2 (A), D10.2 (A), D11.2 (A), Q1.2 (S), Q3.2 (S), R1.1, R31.1, R37.1, R43.1, R164.1, R166.1, R168.1, U7.3 (GND), U7.7 (EP), U9.6 (GND), U10.4 (GND); also elsewhere on the board
unnamed: C23.2, C29.2, L3.1 (+), R13.2, R37.2, TP9.1, U9.2 (EN), U9.4 (VIN)
unnamed: C22.1, L3.2 (-), U9.5 (SW)
unnamed: L4.1 (+), U10.5 (SW)
unnamed: Q3.3 (D), R168.2, R182.1, TP14.1, U10.1 (EN)
unnamed: C39.1, R33.1, R164.2, U7.2 (FB)
unnamed: C22.2, U9.1 (CBST)
unnamed: C27.1, R1.2, R27.1, U9.3 (FB)
unnamed: C33.1, R30.1, R31.2, U10.3 (FB)
unnamed: R163.1, U10.2 (PG)
unnamed: C30.2, C31.2, R14.2, TP10.1, U10.6 (VIN)

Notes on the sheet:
Resistors are 1% 1/16W 0402 unless otherwise noted Capacitors are 10% 50V X7R 0402 unless otherwise noted
3.52V to 4.0V in

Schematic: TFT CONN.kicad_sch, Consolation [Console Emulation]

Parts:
C43: 1u; CAP_NONPOL_0805; Tolerance ±10%; Voltage Rating 50V; Manufacturer Part Number CC0805KKX7R9BB105
C44, C136, C137, C164: 0.1u; CAP_NONPOL_0402; Tolerance ±10%; Voltage Rating 50V; Manufacturer Part Number GRM155R71H104KE14D
C135, C162, C163, C165, C166: 22u; CAP_NONPOL_0805; Tolerance ±20%; Voltage Rating 25V; Manufacturer Part Number CL21A226MAYNNNE
D21, D22: ESD7016MUTAG; UDFN8; Manufacturer Part Number ESD7016MUTAG
D30: SK34A-LTP; DO-214AC; Tolerance NA; Manufacturer Part Number SK34A-LTP
HOLE1, HOLE2, HOLE3, HOLE4: MTG_hole_cir_5mm_pad_3mm_drill
ITEM3: RVT50HQLFWN00; Manufacturer Part Number SM-RVT50HQLFWN00
J3: 62684-402100ALF; Current Rating 0.5A; Voltage Rating 50V; Manufacturer Part Number 62684-402100ALF
L5: PA5003.472NLT; PA5003; Tolerance ±20%; Manufacturer Part Number PA5003.472NLT
R129, R130, R131, R132: 0R; RES_0603; Tolerance 1%; Manufacturer Part Number RC0603JR-070RL
R208, R209, R211: 10K; RES_0402; Tolerance 1%; Manufacturer Part Number RC0402FR-0710KL
R210: 1R5; RES_0603; Tolerance 1%; Manufacturer Part Number RC0603FR-131R5L
R212: 10K; RES_0402; Tolerance 1%; Manufacturer Part Number RC0402FR-0710KL; not fitted
R213: 1R5; RES_0603; Tolerance 1%; Manufacturer Part Number RC0603FR-131R5L; not fitted
R305: 0R; RES_1206; Tolerance 1%; Manufacturer Part Number RC1206JR-070RL
TP45, TP46, TP47: 75 mils; SMT_TP_75_MILS; Manufacturer Part Number NA
U11: AP22913W6-7; SOT-23-6; Load Voltage 1.5V ~ 5.5V; Manufacturer Part Number AP22913W6-7
U26: TPS61169DCKR; SC-70-5; Input Voltage (Min) 2.7V; Input Voltage (Max) 5.5V; Manufacturer Part Number TPS61169DCKR

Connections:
3V3: C44.2, R212.2, R305.1, U11.4 (IN), U11.6 (IN); also elsewhere on the board
/BL_PWM: R208.2, U26.4 (CTRL); also elsewhere on the board
/DSI TO LVDS/LVDS_A.CLK_N: D22.1 (I/O1), J3.24 (CLK_N); also elsewhere on the board
/DSI TO LVDS/LVDS_A.CLK_P: D22.2 (I/O2), J3.23 (CLK_P); also elsewhere on the board
/DSI TO LVDS/LVDS_A.D0_N: D21.1 (I/O1), J3.33 (RD0_N); also elsewhere on the board
/DSI TO LVDS/LVDS_A.D0_P: D21.2 (I/O2), J3.32 (RD0_P); also elsewhere on the board
/DSI TO LVDS/LVDS_A.D1_N: D21.4 (I/O3), J3.30 (RD1_N); also elsewhere on the board
/DSI TO LVDS/LVDS_A.D1_P: D21.5 (I/O4), J3.29 (RD1_P); also elsewhere on the board
/DSI TO LVDS/LVDS_A.D2_N: D21.7 (I/O5), J3.27 (RD2_N); also elsewhere on the board
/DSI TO LVDS/LVDS_A.D2_P: D21.8 (I/O6), J3.26 (RD2_P); also elsewhere on the board
/DSI TO LVDS/LVDS_A.D3_N: D22.4 (I/O3), J3.21 (RD3_N); also elsewhere on the board
/DSI TO LVDS/LVDS_A.D3_P: D22.5 (I/O4), J3.20 (RD3_P); also elsewhere on the board
/TFT CONN/TFT_3V3: C135.2, C136.2, C137.2, J3.8 (L/R), J3.38 (VDD), J3.39 (VDD), R209.2, TP45.1, U11.1 (OUT)
/~TFT_RST: R211.2, R212.1, U11.3 (EN); also elsewhere on the board
GND: C43.1, C44.1, C135.1, C136.1, C137.1, C162.1, C163.1, C164.1, C165.1, C166.1, D21.3 (VBUS), D21.6 (GND), D22.3 (VBUS), D22.6 (GND), J3.7 (U/D), J3.11 (GND), J3.13 (SELB), J3.16 (GND), J3.19 (GND), J3.22 (GND), J3.25 (GND), J3.28 (GND), J3.31 (GND), J3.34 (GND), R129.2, R130.2, R131.2, R132.2, R208.1, R210.1, R211.1, R213.1, U11.2 (GND), U11.5 (GND), U26.2 (GND); also elsewhere on the board
unnamed: D30.2 (A), L5.2, U26.1 (SW)
unnamed: C162.2, C163.2, D30.1 (K), J3.1 (LED+), J3.2 (LED+), TP46.1
unnamed: HOLE1.1, R132.1
unnamed: HOLE2.1, R129.1
unnamed: HOLE3.1, R130.1
unnamed: HOLE4.1, R131.1
unnamed: C43.2, J3.35 (STBYB), J3.36 (~RESET), R209.1
unnamed: J3.9 (LED-), J3.10 (LED-), R210.2, R213.2, TP47.1, U26.3 (FB)
unnamed: C164.2, C165.2, C166.2, L5.1, R305.2, U26.5 (VIN)

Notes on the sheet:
PIN1 CONN = PIN40 TFT
0.204V / 0.14A ~= 1.46R
Resistors are 1% 1/16W 0402 unless otherwise noted Capacitors are 10% 50V X7R 0402 unless otherwise noted

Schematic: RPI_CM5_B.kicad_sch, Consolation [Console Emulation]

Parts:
C110: 0.1u; CAP_NONPOL_0402; Tolerance ±10%; Voltage Rating 50V; Manufacturer Part Number GRM155R71H104KE14D
ITEM1: Raspberry PI CM4 and CM5 symbol; rPI_CM4_CM5
J12: RPI_CMx_B; DF40HC(3.0)-100DS-0.4V; Current Rating 0.5A; Voltage Rating 150V; Manufacturer Part Number DF40HC(3.0)-100DS-0.4V(58)
J18: 61300411121; HEADER_4P_2_54MM; Voltage Rating 250V; Current Rating 3A; Manufacturer Part Number 61300411121; not fitted
MTG1, MTG2, MTG3, MTG4: 9774030951R; 9774030151R; Manufacturer Part Number 9774030951R
R120: 22R; RES_0402; Tolerance 1%; Manufacturer Part Number RC0402FR-0722RL
R156, R177: 10K; RES_0402; Tolerance 1%; Manufacturer Part Number RC0402FR-0710KL
R183: 6K04; RES_0402; Tolerance 1%; Manufacturer Part Number RC0402FR-076K04P
TP23: 75 mils; SMT_TP_75_MILS; Manufacturer Part Number NA

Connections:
3V3: R156.1; also elsewhere on the board
/CM5_CONN_B/DSI1.CLK_N: J12.87 (DSI1_CLK_N); also elsewhere on the board
/CM5_CONN_B/DSI1.CLK_P: J12.89 (DSI1_CLK_P); also elsewhere on the board
/CM5_CONN_B/DSI1.D0_N: J12.75 (DSI1_D0_N); also elsewhere on the board
/CM5_CONN_B/DSI1.D0_P: J12.77 (DSI1_D0_P); also elsewhere on the board
/CM5_CONN_B/DSI1.D1_N: J12.81 (DSI1_D1_N); also elsewhere on the board
/CM5_CONN_B/DSI1.D1_P: J12.83 (DSI1_D1_P); also elsewhere on the board
/CM5_CONN_B/DSI1.D2_N: J12.93 (DSI1_D2_N); also elsewhere on the board
/CM5_CONN_B/DSI1.D2_P: J12.95 (DSI1_D2_P); also elsewhere on the board
/CM5_CONN_B/DSI1.D3_N: J12.94 (DSI1_D3_N); also elsewhere on the board
/CM5_CONN_B/DSI1.D3_P: J12.96 (DSI1_D3_P); also elsewhere on the board
/CM5_CONN_B/HDMI0.CEC: J12.51 (HDMI0_CEC); also elsewhere on the board
/CM5_CONN_B/HDMI0.CLK_N: J12.90 (HDMI0_CLK_N); also elsewhere on the board
/CM5_CONN_B/HDMI0.CLK_P: J12.88 (HDMI0_CLK_P); also elsewhere on the board
/CM5_CONN_B/HDMI0.D0_N: J12.84 (HDMI0_TX0_N); also elsewhere on the board
/CM5_CONN_B/HDMI0.D0_P: J12.82 (HDMI0_TX0_P); also elsewhere on the board
/CM5_CONN_B/HDMI0.D1_N: J12.78 (HDMI0_TX1_N); also elsewhere on the board
/CM5_CONN_B/HDMI0.D1_P: J12.76 (HDMI0_TX1_P); also elsewhere on the board
/CM5_CONN_B/HDMI0.D2_N: J12.72 (HDMI0_TX2_N); also elsewhere on the board
/CM5_CONN_B/HDMI0.D2_P: J12.70 (HDMI0_TX2_P); also elsewhere on the board
/CM5_CONN_B/HDMI0.HPD: J12.53 (HDMI0_HPD); also elsewhere on the board
/CM5_CONN_B/HDMI0.SCL: J12.100 (HDMI0_SCL); also elsewhere on the board
/CM5_CONN_B/HDMI0.SDA: J12.99 (HDMI0_SDA); also elsewhere on the board
/CM5_CONN_B/RP2350_VBUS: R120.2, TP23.1; also elsewhere on the board
/CM5_CONN_B/USB2_RP2350.USB_N: J12.65 (DSI0_D1_P/USB3_1_N); also elsewhere on the board
/CM5_CONN_B/USB2_RP2350.USB_P: J12.63 (DSI0_D1_N/USB3_1_P); also elsewhere on the board
/CM5_CONN_B/USB_PROG_N: J12.3 (USB_N), J18.3
/CM5_CONN_B/USB_PROG_OTG_ID: C110.2, J12.1 (USB_OTG_ID), R177.2, R183.1; also elsewhere on the board
/CM5_CONN_B/USB_PROG_P: J12.5 (USB_P), J18.2
/USB2_DOCK.USB_N: J12.36 (CAM0_D1_P/USB3_0_N); also elsewhere on the board
/USB2_DOCK.USB_P: J12.34 (CAM0_D1_N/USB3_0_P); also elsewhere on the board
GND: C110.1, J12.7 (GND), J12.8 (GND), J12.13 (GND), J12.14 (GND), J12.19 (GND), J12.20 (GND), J12.25 (GND), J12.26 (GND), J12.31 (GND), J12.32 (GND), J12.37 (GND), J12.38 (GND), J12.44 (GND), J12.50 (GND), J12.55 (GND), J12.56 (GND), J12.61 (GND), J12.62 (GND), J12.67 (GND), J12.68 (GND), J12.73 (GND), J12.74 (GND), J12.79 (GND), J12.80 (GND), J12.85 (GND), J12.86 (GND), J12.91 (GND), J12.92 (GND), J12.97 (GND), J12.98 (GND), J18.1, MTG1.1, MTG2.1, MTG3.1, MTG4.1, R177.1; also elsewhere on the board
unnamed: J12.11 (VDAC_COMP/VBUS_EN), R120.1
unnamed: J12.2 (~PCIe_CLK_REQ), R156.2
unnamed: J18.4, R183.2

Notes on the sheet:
Resistors are 1% 1/16W 0402 unless otherwise noted Capacitors are 10% 50V X7R 0402 unless otherwise noted
GND D+ D- 5V
USB Boot CM5

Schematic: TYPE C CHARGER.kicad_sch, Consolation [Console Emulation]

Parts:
C1: 47nF; CAP_NONPOL_0402; Tolerance ±10%; Voltage Rating 50V; Manufacturer Part Number CC0402KRX7R9BB473
C2, C5, C10: 1u; CAP_NONPOL_0805; Tolerance ±10%; Voltage Rating 50V; Manufacturer Part Number CC0805KKX7R9BB105
C3, C4, C9: 10u; CAP_NONPOL_1210; Tolerance ±10%; Voltage Rating 50V; Manufacturer Part Number C3225X7R1H106K250AC
C6, C7, C13: 22u; CAP_NONPOL_0805; Tolerance ±20%; Voltage Rating 25V; Manufacturer Part Number CL21A226MAYNNNE
C8: 4.7u; CAP_NONPOL_0805; Tolerance ±10%; Voltage Rating 25V; Manufacturer Part Number TMK212AB7475KG-T
C90, C92: 0.1u; CAP_NONPOL_0402; Tolerance ±10%; Voltage Rating 50V; Manufacturer Part Number GRM155R71H104KE14D
D26: ESD7016MUTAG; UDFN8; Manufacturer Part Number ESD7016MUTAG
D29: SMAJ20A; DO-214AC; Tolerance NA; Manufacturer Part Number SMAJ20A
J4: 12401598E4#2A; Voltage Rating 100V; Current Rating 5A; Manufacturer Part Number 12401598E4#2A
J5: S2B-PH-K-S; Voltage Rating 100V; Current Rating 2A; Manufacturer Part Number S2B-PH-K-S
J10: 61300311121; HEADER_3P_2_54MM; Voltage Rating 250V; Current Rating 3A; Manufacturer Part Number 61300311121; not fitted
L1: PA5003.102NLT; PA5003; Tolerance ±20%; Manufacturer Part Number PA5003.102NLT
R3, R5, R6: 100R; RES_0402; Tolerance 1%; Manufacturer Part Number RC0402FR-07100RL
R7: 103AT-4-70374; HEADER_2P_2_54MM; Tolerance ±1%; Manufacturer Part Number 103AT-4-70374
R104, R105: 4K7; RES_0402; Tolerance 1%; Manufacturer Part Number RC0402FR-074K7L; not fitted
R148, R173, R174: 10K; RES_0402; Tolerance 1%; Manufacturer Part Number RC0402FR-0710KL; not fitted
R149, R162: 10K; RES_0402; Tolerance 1%; Manufacturer Part Number RC0402FR-0710KL
R153: 0R; RES_0402; Tolerance 1%; Manufacturer Part Number RC0402FR-071KL; not fitted
TP37, TP38, TP39, TP40, TP41, TP42, TP43, TP44, TP49: 75 mils; SMT_TP_75_MILS; Manufacturer Part Number NA
U1: BQ25640VDLR; WQFN-22-EP; Input Voltage (Max) 18V; Output Voltage 2.56V ~ 4.0V; Manufacturer Part Number BQ25640VDLR

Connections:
3V3: R104.2, R105.2, R148.2, R149.2, R162.2, R174.1; also elsewhere on the board
/CM5_CONN_A/~BAT_CHRG_INT: R149.1, TP42.1, U1.8 (~INT); also elsewhere on the board
/I2C2.I2C_SCL: R105.1, U1.16 (SCL); also elsewhere on the board
/I2C2.I2C_SDA: R104.1, U1.15 (SDA); also elsewhere on the board
/Power Supply/VSYS: C6.2, C7.2, C13.2, L1.2 (-), TP44.1, U1.13 (SYS); also elsewhere on the board
/TYPE C CHARGER/BAT+: C9.2, C10.2, C92.2, J5.2, R3.1, TP38.1, U1.14 (BAT)
/TYPE C CHARGER/REGN: C8.1, R5.2, U1.19 (REGN)
/TYPE C CHARGER/~BAT_CHRG_EN: J10.2, U1.11 (~CE); also elsewhere on the board
/TYPE C CHARGER/~BAT_CHRG_PG: R162.1, TP41.1, U1.9 (~PG); also elsewhere on the board
/USB2_DOCK.USB_N: D26.5 (I/O4), J4.A7 (D-), J4.B7 (D-); also elsewhere on the board
/USB2_DOCK.USB_P: D26.4 (I/O3), J4.A6 (D+), J4.B6 (D+); also elsewhere on the board
/~BAT_CHRG_RST: R148.1, TP43.1, U1.17 (~QON); also elsewhere on the board
GND: C2.1, C3.1, C4.1, C5.1, C6.1, C7.1, C8.2, C9.1, C10.1, C13.1, C90.1, C92.1, D26.3 (VBUS), D26.6 (GND), D29.2 (A), J4.A1 (GND), J4.A12 (GND), J4.B1 (GND), J4.B12 (GND), J4.C1 (SHLD), J5.1, R6.1, R7.1, R173.1, U1.5 (PGND), U1.18 (PGND), U1.23 (PAD); also elsewhere on the board
unnamed: D26.1 (I/O1), J4.A5 (CC1), TP39.1, U1.1 (CC1)
unnamed: D26.8 (I/O6), J4.B5 (CC2), TP40.1, U1.22 (CC2)
unnamed: C2.2, C3.2, D29.1 (K), J4.A4 (VBUS), J4.A9 (VBUS), J4.B4 (VBUS), J4.B9 (VBUS), TP37.1, U1.2 (VBUS)
unnamed: J10.1, R173.2
unnamed: J10.3, R174.2
unnamed: C1.1, L1.1 (+), U1.4 (SW)
unnamed: R3.2, U1.12 (BATP)
unnamed: C1.2, U1.6 (BTST)
unnamed: R153.2, U1.7 (NC/REGTS)
unnamed: C4.2, C5.2, C90.2, U1.3 (PMID)
unnamed: R5.1, R6.2, R7.2, TP49.1, U1.10 (TS)

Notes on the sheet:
Close to BQ25640
For debug / DVT
Value TBD
Battery connector orientation
Has internal PD
Resistors are 1% 1/16W 0402 unless otherwise noted Capacitors are 10% 50V X7R 0402 unless otherwise noted
Has internal PU

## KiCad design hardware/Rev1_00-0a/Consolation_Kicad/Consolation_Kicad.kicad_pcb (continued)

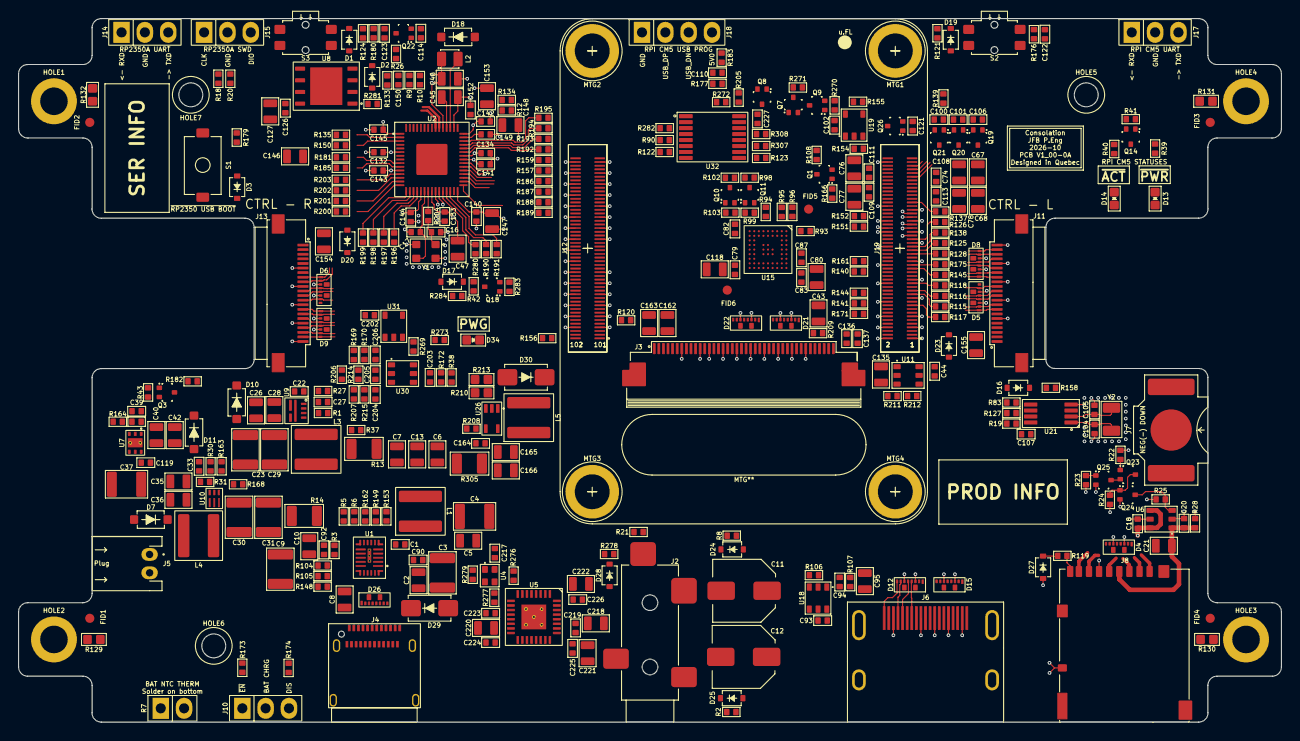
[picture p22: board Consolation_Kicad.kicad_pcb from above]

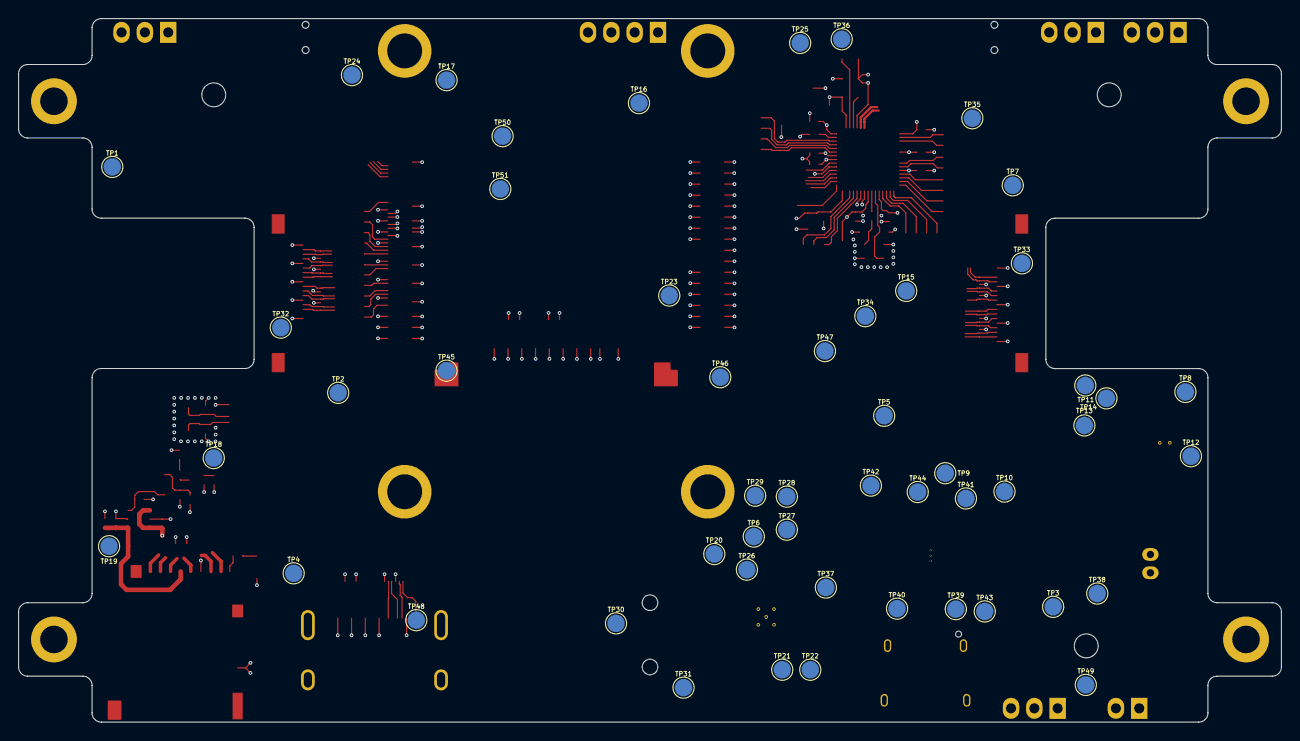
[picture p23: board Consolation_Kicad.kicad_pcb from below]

Board: 6 copper layers, 137.5 x 76.6 mm, 434 parts (51 on the bottom side), 244 nets.

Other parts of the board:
MTG**: Untitled; SLOT_TH_25_5mm

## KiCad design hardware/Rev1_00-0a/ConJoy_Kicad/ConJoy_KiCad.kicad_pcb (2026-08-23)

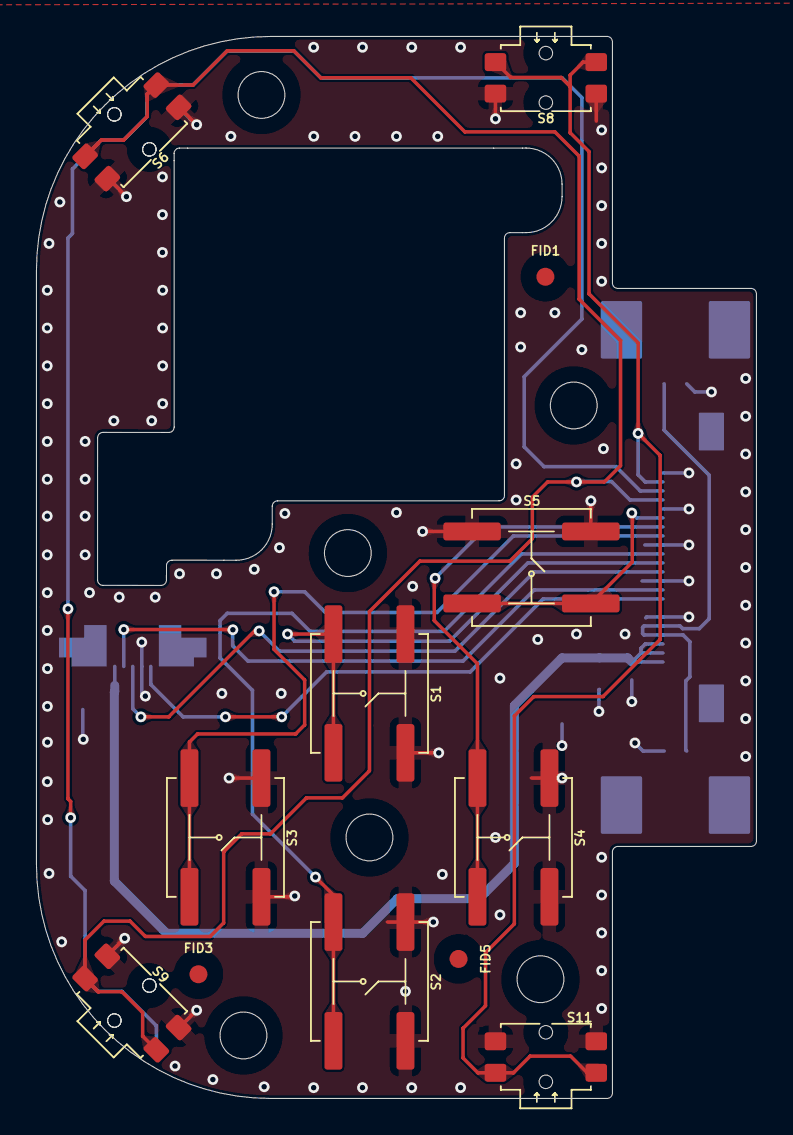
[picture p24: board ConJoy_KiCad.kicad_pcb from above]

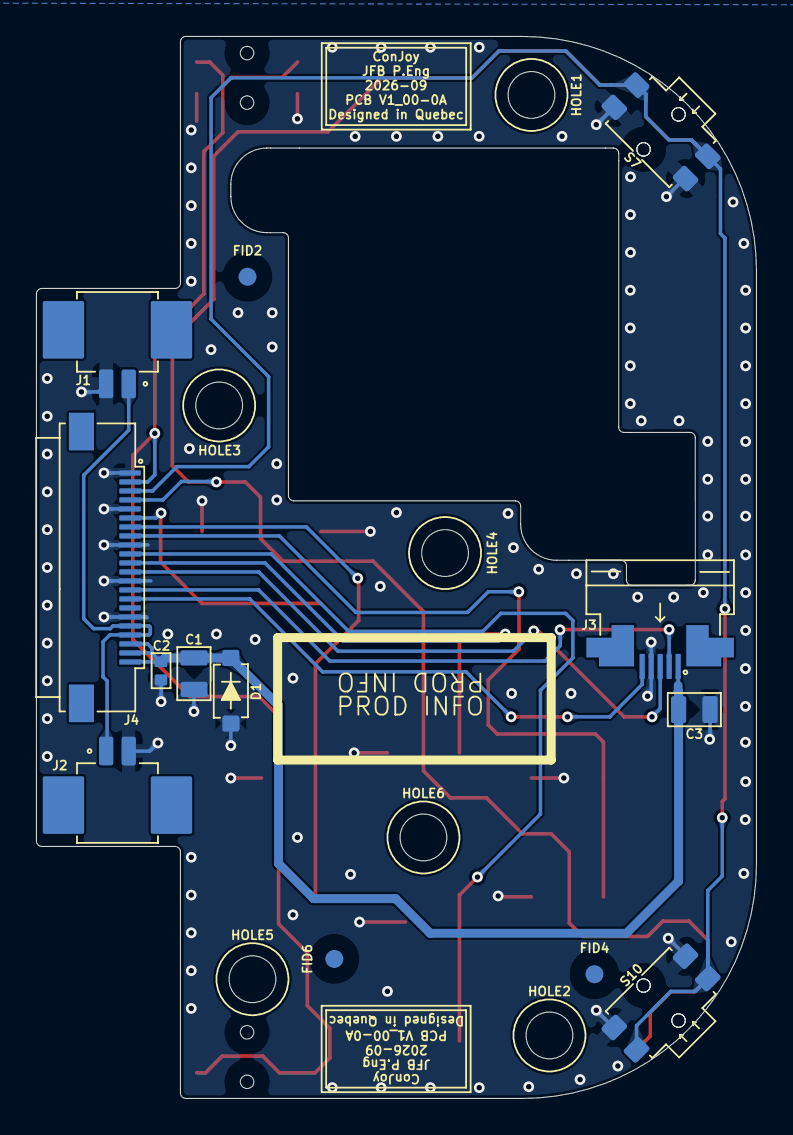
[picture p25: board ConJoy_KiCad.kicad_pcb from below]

Board: 2 copper layers, 40.0 x 59.0 mm, 31 parts (19 on the bottom side), 14 nets.

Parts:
C1, C3: 1u; CAP_NONPOL_0805
C2: 0.1u; CAP_NONPOL_0402
D1: MMSZ5226B-7-F; SOD-123
FID1, FID2, FID3, FID4, FID5, FID6: FIDUCIAL
HOLE1, HOLE2, HOLE3, HOLE4, HOLE5, HOLE6: NPTH_M2
J1, J2: 0532610271
J3: SFV5R-1STE1HLF; SFV5R-1ST
J4: 5051102291
S1, S2, S3, S4, S5: EVQ-Q2P03W; EVQQ2
S6, S7, S8, S9, S10, S11: TL1014BF160QG; TL1014B

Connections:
3V3: C1.2, C2.2, C3.2, D1.1 (K), J3.1, J4.20, J4.21, J4.22
/L_DPAD_DOWN/R_BTN_B: J4.10, S2.2
/L_DPAD_LEFT/R_BTN_X: J4.8, S3.2
/L_DPAD_RIGHT/R_BTN_Y: J4.7, S4.2
/L_DPAD_UP/R_BTN_A: J4.11, S1.2
/L_HOME/R_EXTRA: J4.2, S8.2, S11.2
/L_R_L1_TRIG: J4.4, S6.2, S9.2
/L_R_L2_TRIG: J4.3, S7.2, S10.2
/L_R_SPKOUT: J1.1, J2.1, J4.18, J4.19
/L_R_THUMBST_SW: J3.3, J4.12
/L_R_THUMBST_X: J3.5, J4.15
/L_R_THUMBST_Y: J3.2, J4.14
/L_START/R_SELECT: J4.6, S5.2
GND: C1.1, C2.1, C3.1, D1.2 (A), J1.2, J2.2, J3.4, J4.1, J4.5, J4.9, J4.13, J4.17, S1.1, S2.1, S3.1, S4.1, S5.1, S6.1, S7.1, S8.1, S9.1, S10.1, S11.1

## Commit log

2026-07-10 Initial commit of Consolation [Consolation Emulation]
    [Consolation_Kicad.kicad_pcb, Consolation_Kicad.kicad_sch]
2026-07-14 Update block diagram for battery charger + power delivery solution based on BQ25640 Start Pinout documentation for RP2350-based joystick controller Create new schematic pages
    [Consolation - PinMux.ods, Consolation - Power Table.ods, Consolation_Kicad.kicad_sch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]
2026-07-16 Work on block diagram
    [CONTROLLER.kicad_sch, Consolation_Kicad.kicad_sch, TYPE C CHARGER.kicad_sch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]
2026-07-18 Update block diagram Updage charger schematic page with BQ25640 preliminary implementation
    [CONTROLLER.kicad_sch, RPI_CM5_A.kicad_sch, TYPE C CHARGER.kicad_sch]
2026-07-22 Add part number of codec to block diagram Add codec and hdmi schematic sheets
    [CODEC.kicad_sch, Consolation - PinMux.ods, Consolation - Power Table.ods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]
2026-07-25 Update schematics, block diagram and pin mux (good progress G)
    [CODEC.kicad_sch, CONTROLLER.kicad_sch, Consolation - PinMux.ods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]
2026-07-28 Update PinMux & Schematics
    [CODEC.kicad_sch, CONTROLLER.kicad_sch, Consolation - PinMux.ods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]
2026-08-02 Work on ConJoy [Consolation Joycon] Work on Consolation [Console Emulation]
    - Adjust controller pinout
    - Design controller for 1-PCB fits both side (reversible design for L-R controller)
    - Preliminary PCB for 3d modeling
    [CODEC.kicad_sch, CONTROLLER.kicad_sch, ConJoy_KiCad.kicad_pcb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]
2026-08-03 Switch speaker pinout following footprint and 3d model review Add mounting holes
    [ConJoy_KiCad.kicad_pcb, ConJoy_KiCad.kicad_sch]
2026-08-04 ConJoy mostly ready for alpha prototype. Confirm few other potential tweaks at 3d printing
    [CODEC.kicad_sch, CONTROLLER.kicad_sch, ConJoy_KiCad.kicad_pcb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]
2026-08-05 Commit ConJoy design + output files (ready for manufacturing or REV 1.00-0A)
    [ConJoy-1.00-0A-STEP-LEFT.step, ConJoy-1.00-0A-STEP-RIGHT.step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]
2026-08-05 Add a lillllllll more clearance on inner cutout of ConJoy for Flat Flex cable of joystick
    [ConJoy-1.00-0A-STEP-LEFT.step, ConJoy-1.00-0A-STEP-RIGHT.step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]
2026-08-06 Work on block diagram and top-level schematic sheet Work on PinMux
    [CONTROLLER.kicad_sch, Consolation - PinMux.ods, Consolation_Kicad.kicad_sch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]
2026-08-07 Adjust mounting holes on ConJoy to ease case 3d modeling
    [ConJoy-1.00-0A-STEP-LEFT.step, ConJoy-1.00-0A-STEP-RIGHT.step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]
2026-08-08 Major update to consolation schematics to include - Power supply - RESET SUPERVISOR - Review of GPIO and pinmux
    [CODEC.kicad_sch, CONTROLLER.kicad_sch, Consolation - PinMux.ods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]
2026-08-15 Move joystick connector to bottom side for easier access during assembly Re-generate all output files
    [ConJoy-1.00-0A-STEP-LEFT.step, ConJoy-1.00-0A-STEP-RIGHT.step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]
2026-08-15 Move Joystick connector to bottom side of PCB Remove duplicate decoupling + bulk capacitors
    [ConJoy_KiCad.kicad_pcb, ConJoy_KiCad.kicad_sch]
2026-08-15 Removed unnecessary functions (USB2 mux, CapTouch) Adjusted 220uF alum capacitor for codec (slimmer version)
    [CODEC.kicad_sch, CONTROLLER.kicad_sch, Consolation_Kicad.kicad_pcb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]
2026-08-17 Move Joycon connector slightly up to improve & ease up FPC / FFC cable connectivity
    [ConJoy-1.00-0A-STEP-LEFT.step, ConJoy-1.00-0A-STEP-RIGHT.step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]
2026-08-17 Move Joycon connector slightly up to ease FFC / FPC connector handling and connecting
    [ConJoy_KiCad.kicad_pcb]
2026-08-18 Component preliminary placement
    [CODEC.kicad_sch, Consolation_Kicad.kicad_pcb, Consolation_Kicad.kicad_sch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]
2026-08-19 Preliminary placement of Consolation continues
    [CODEC.kicad_sch, CONTROLLER.kicad_sch, Consolation - PinMux.ods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]
2026-08-22 Work on preliminary placement + RP2350A fanout
    [CONTROLLER.kicad_sch, Consolation_Kicad.kicad_pcb, Consolation_Kicad.kicad_sch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]
2026-08-23 Update ConJoy L2 trigger (2-level trigger instead) Update ConJoy all output files accordingly
    Work on Consolation preliminary placement
    [CODEC.kicad_sch, CONTROLLER.kicad_sch, ConJoy-1.00-0A-STEP-LEFT.step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]
2026-08-29 Continue preliminary placement To do : Power supplies + Type C charger
    [CODEC.kicad_sch, CONTROLLER.kicad_sch, Consolation_Kicad.kicad_pcb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]
2026-09-20 Preliminary placement done Add test points to PCB
    [CODEC.kicad_sch, CONTROLLER.kicad_sch, Consolation_Kicad.kicad_pcb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]
2026-10-12 Preliminary routing (DiffPairs, Power planes) in progress Slight changes to schematics to accommodate routing
2026-10-31 Work on DFM, Pick N Place file accuracy, BOM accuracy Generating output files regularly through incremental updates
2026-11-01 2nd DFM review push Added manufacturing directives in gerber files, modified few traces width and removed few teardrops
2026-11-01 Update ConJoy fabrication files exports, added PCB manufacturing informations
2026-11-03 Following schematic design review: - Flip D17 - Add anti-aliasing low-pass filter on Controller ADC inputs - Adjust SN65DSI84 Vcore capacitor to 1uf - Adjust RP2350A XOUT series resistor to 1k Push c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
2026-11-03 Following DFM review, adjust copper to copper and copper to hole clearance on few traces
2026-11-04 Add ESD diodes on USB header for CM5 programming and bring-up Re-generate all output files
2026-11-05 Adjust ConJoy PCB following final DFM review Status set to released, ready to order
2026-11-05 Save Conjoy PCB project
2026-11-05 Adjust BOM to address non available parts Re-generate schematics, BOM, netlist, PCB PDF
2026-11-07 Add device tree overlays and generic config file Create prototype tracker
2026-11-14 Add working gerbers to repository
